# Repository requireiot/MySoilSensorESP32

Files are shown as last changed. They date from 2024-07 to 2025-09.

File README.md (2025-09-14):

MySoilSensorESP32 -- a multi-channel soil moisture sensor with long battery life
----
This is part of my home automation setup. For details, see my [blog](https://requireiot.com/my-home-automation-story-part-1/).

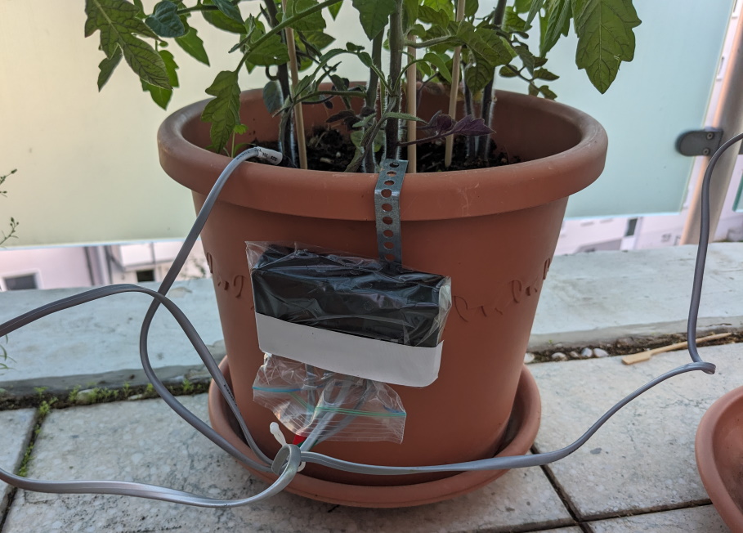
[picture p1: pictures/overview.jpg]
 

- [MySoilSensorESP32 -- a multi-channel soil moisture sensor with long battery life](#mysoilsensoresp32----a-multi-channel-soil-moisture-sensor-with-long-battery-life)
- [Objective](#objective)
- [Design decisions](#design-decisions)
  - [How to make it waterproof-ish](#how-to-make-it-waterproof-ish)
  - [How to communicate](#how-to-communicate)
  - [Minimize power consumption](#minimize-power-consumption)
- [Building blocks](#building-blocks)
- [Hardware](#hardware)
- [Batteries](#batteries)
- [Firmware](#firmware)
- [MQTT messages](#mqtt-messages)
- [Over-the-air update](#over-the-air-update)
  - ['Classic' OTA firmware update](#classic-ota-firmware-update)
  - [OTA firmware download from a HTTP server](#ota-firmware-download-from-a-http-server)
- [Debugging support](#debugging-support)
- [Power consumption and battery life](#power-consumption-and-battery-life)
  - [Wake time](#wake-time)
  - [Actual power consumption](#actual-power-consumption)
- [Lessons learned](#lessons-learned)
  - [Analog-to-digital conversion with the ESP32](#analog-to-digital-conversion-with-the-esp32)
  - [Some things are outside of my control](#some-things-are-outside-of-my-control)
  - [An almost easy project](#an-almost-easy-project)
  - [Bad luck with channel 13](#bad-luck-with-channel-13)

## Objective
In summer, I have a lot of potted plants out on the balcony, and I need to know when 
to water them. Indoors, most of my home automation gadgets are based on 
[MySensors](https://www.mysensors.org/), but out on the balcony the signal is 
too weak, so I needed something WiFi-based, but without the high battery 
consumption typical of WiFi solutions.

## Design decisions

### How to make it waterproof-ish

There will be rain out on the balcony, so the modules need to be waterproof-ish. 
Real waterproof sealed cases are expensive, so I opted for a cheap plastic case 
with a Ziploc bag over it, with the opening facing down ... good enough for the 
intended use case.

### How to communicate

To exchange information between the soil sensors and the home automation system 
(soil moisture and performance characteristics from the device, commands to 
change operating parameters or start over-the-air updates to the device), 
I could think of the following technologies:
1. **MQTT**. *Pro*: I already have an MQTT broker running, and this is independent 
   of a specific home automation system. *Con*: Communication is a bit unpredictable, as I found out
2. **HTTP** requests to a REST API, e.g. for OpenHAB. *Pro*: More deterministic, 
   you know exactly when a message has been accepted. *Con*: Specific for one 
   home automation system

I went for (1).

### Minimize power consumption

- a bare ESP32-WROOM module is better than a development module -- probably due 
  to the voltage regulators and USB interfaces on those modules. Power 
  consumption during deep sleep, with a bare ESP32-WROOM, powered from 2x 
  AAA battery, is under **10µA**.
- to avoid any power loss through a voltage regulator, I am running the ESP32 
  directly from a pair of AAA batteries. Newer processors will work down to 2.3V, 
  I just had to make sure the soil moisture sensor also works below 3V (see below)
- the soil sensors are *powered* by GPIO pins, which are turned off during sleep
- to minimize the time the processor is awake, and in particular the time that 
  WiFi is active, I try to reconnect to WiFi using previously established SSID, 
  IP address and channel number, which are cached in RTC memory

## Building blocks

- an ESP32 module with custom Arduino-based software
- two AAA batteries, which should last for more than a year
- up to 4 cheap capacitive soil sensors, of the kind you find on Aliexpress for 
  less than a Euro
- my home network, with a DHCP server assigning pseudo-static IP addresses to 
  everybody, based on MAC address
- my home automation system, with an MQTT broker and OpenHAB for visualization 
  and control

## Hardware

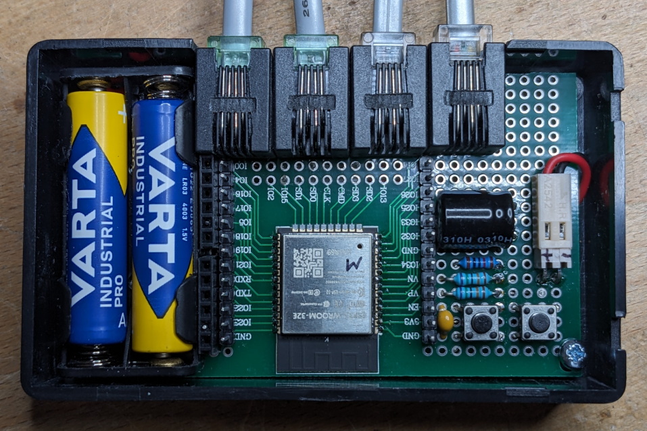
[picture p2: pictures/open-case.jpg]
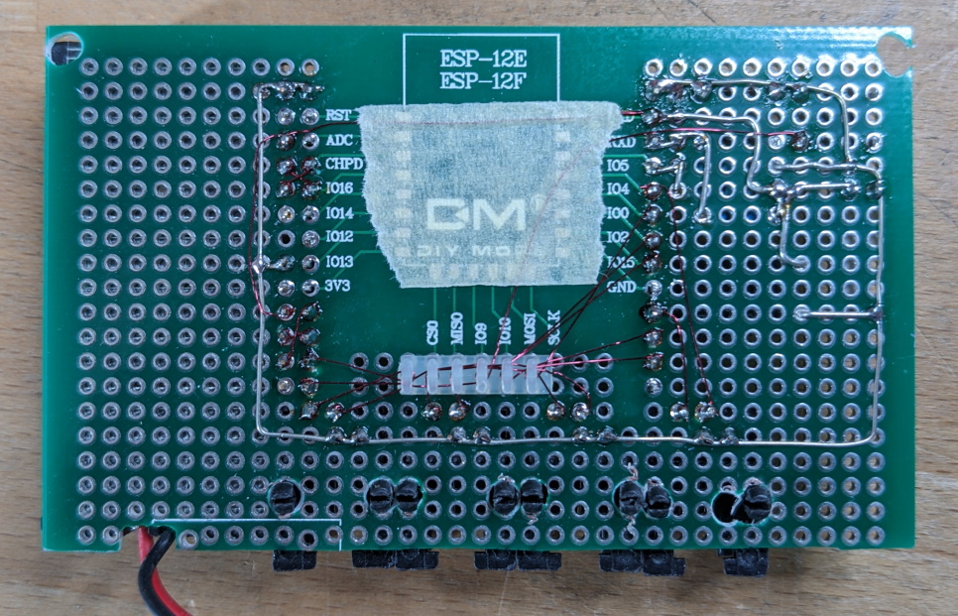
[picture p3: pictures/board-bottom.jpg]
 

The hardware is very simple, see the [schematic](hardware/MySoilSensorESP32.pdf) 
and the pictures above. 

For development and debugging, I added pin connectors to connect to FTDI-232 style 
USB-to-serial interfaces, one for the primary UART (for firmware upload) and one 
for UART#2, where the software outputs logging messages. For a production system, 
this is not necessary and can be left out, of course.

## Batteries

One option is to power the ESP32 directly from two AA or AAA batteries. The battery life calculations reported below apply to this configuration.

As an alternative, I have built a few units with a _rechargable_ battery and a solar panel for charging, attached to the outside of the case. This works as well, if the case can be positioned such that the solar panel faces the sun. Here is the bill of materials for this variant:
* a "5V 75mA 80x45mm" solar panel, from Aliexpress, ca. €1
* a TP4056 battery management module, from Aliexpress, ca. €0.20
* a small Li-ion battery, 3.7V at 1000 mA, from Reichelt (p/n AKKU 30389), €1.80 ... this is a noname replacement battery for some GPS receiver. I have also used a replacement battery for a 1st gen Apple iPod nano.
* a low-drop, low quescent current voltage regulator for 3.3V, HT7833

## Firmware

The software was developed using [Platformio](https://platformio.org/). Just 
download the repository contents into an empty folder, and open that folder as 
a Platformio project. 

In folder `src/`, rename file `myauth_sample.h` to `myauth.h` and enter your 
Wifi SSID and password.

In the top folder, rename file `devices.ini.sample` to `devices.ini` and enter the hostnames and IP addresses for your environment. I built multiple units and wanted to update each of them over-the-air, so I needed a separate entry for each, specifying each IP address as assigned by my DHCP server.

Edit file `platformio.ini` and enter the COM port for your 
environment. 

I used a 7x9 cm prototype board for ESP32 and ESP8266 boards, cut to fit inside 
a 100x60x25 mm plastic case. The soil sensors are connected via cables with an 
RJ12 6P4C connecter on the module end, for easy connection "in the field".

The capacitive soil sensors I got from Aliexpress had an NE555 chip that only 
works down to 3.0V, whereas the ESP32 itself will still work when the battery 
voltage is as low as 2.5V, so I replaced the NMOS NE555 with the CMOS version 
ILC555D, which work down to 2.0V. I also bypassed the voltage regulator on the 
sensor board.

## MQTT messages

The device publishes to MQTT topics that include its own hostname:
- to <code>soil/__hostname__/debug</code> it publishes a JSON string with various 
  internal parameters, such as battery voltage, uptime etc., once every 12 hours
- to <code>soil/__hostname__/state</code> it publishes a JSON string with
   measurement results, once every hour 
- to <code>soil/__hostname__/wifi</code> it publishes a JSON string with some 
  performance metrics, such as Wifi quality, the time needed to connect to the 
  Wifi access point, etc., once every hour 
- it subscribes to <code>soil/__hostname__/cmd</code> to enable over-the-air 
  updates (see below)
- it subscribes to <code>soil/__hostname__/config</code> to receive a JSON-format 
  string enable to change some operating parameters (see source code for details)

For example, my device has the hostname `esp32-D80270`, so it will publish to 
`soil/esp32-D80270/state` etc.

## Over-the-air update

The device supports OTA firmware updates, despite the fact that it is in deep 
sleep most of the time. How? When it wakes up, it subscribes to MQTT topic 
<code>soil/_hostname_/cmd</code> (see above).

### 'Classic' OTA firmware update

When the device wakes up, and it finds a retained MQTT message <code>soil/_hostname_/cmd</code> with the payload of `ota`, it enables ArduinoOTA and waits for an upload of new firmware, instead of going to sleep. 
It also deletes the topic to acknowledge that it has received the command. 

To perform an OTA firmware update,
1. compile your code for the target that has "-ota" in its name (look at 
   `platformio.ini` and adjust the IP address or device hostname to match your 
   conguration)
1. publish a retained message for topic <code>soil/_hostname_/cmd</code> with 
   a payload of `ota` For my device `esp32-D80270`, I run the following shell 
   comand on the home automation server: <br> 
 `mosquitto_pub -r -t "soil/esp32-D80270/cmd" -m "ota"`
1. wait for the item to disappear. I watch it with a tool like 
   [MQTT Explorer](https://mqtt-explorer.com/), or run this shell command 
   repeatedly <br/> `mosquitto_sub -t "soil/esp32-D80270/cmd"`  
1. upload your firmware via Platformio

### OTA firmware download from a HTTP server

When the device wakes up, and it finds a retained MQTT message <code>soil/_hostname_/cmd</code> with the payload of `update`, it attempts to download a new firmware file named <code>_hostname_-firmware.bin</code> from a HTTP server on the local network. The server name can be configured in source code. After a successful download, it will install the new firmware and the restart. It also deletes the topic to 
acknowledge that it has received the command. 

To perform this kind of OTA firmware update,
1. compile your code for the `env:http` target 
2. when you "upload", the `firmware.bin` file will just be copied to your HTTP server, and renamed to <code>MySoilSensorESP32.bin</code>. 
3. publish a retained message for topic <code>soil/_hostname_/cmd</code> with 
   the payload of `update` For my device `esp32-D80270`, I run the following shell 
   comand on the home automation server: <br> 
 `mosquitto_pub -r -t "soil/esp32-D80270/cmd" -m "update"`
1. The next time the module wakes up, it will perform the update. You can tell that the update has happened when the MQTT item disappears. I watch it with a tool like [MQTT Explorer](https://mqtt-explorer.com/), or run this shell command 
   repeatedly <br/> `mosquitto_sub -t "soil/esp32-D80270/cmd"`  

The advantage of this type of OTA update is that you can build firmware for multiple devices, publish the <code>soil/_hostname_/cmd</code> topic for each device, and then go away and forget about it. Each device will update itself the next time it wakes up as scheduled.

## Debugging support

The software can print a lot of logging messages to UART#2 (GPIO pins 16 and 17), 
to which I connect an optically isolated FTDI-style USB to serial module. This 
was really helpful for understanding what goes on, and where delays occur.

The logging messages are normally suppressed. To enable logging, edit `platformio.ini`, in the general `[env]` section or an `[env:xyz]` section for a specific device, to contain
```
build_flags = 
  -D CORE_DEBUG_LEVEL=3
```

## Power consumption and battery life

### Wake time

As explained above, the time the module stays awake each measurement cycle is 
important for overall power consumption, so I investigated the wake time in some 
detail.

I built several of these units, some connected directly to the Wifi access point 
(a AVM Fritzbox 7530), and some via a Wifi repeater (a Fritzbox 7490 operating as a mesh repeater), over a distance of 3-5m, through a massive outer brick wall (or maybe through a 
window).

On average, the wake time is about **1000 ms** for all units. Now and then, maybe 
once or twice a day, the wake time is much larger, above **1500 ms**. This appeared
to happen mostly when the Wifi access point had switched to a different Wifi 
channel. When I configured my access point to use a fixed Wifi channel, these 
long wake time events became less frequent.

### Actual power consumption

These factors contribute to power consumption or battery drain, 
in decreasing order of importance:
1. the self-discharge of the AAA batteries, according to [[1]](http://www.gammon.com.au/power), 
about 35 µA or **0.84 mAh** per day 
1. wake time with WiFi ON, 140 mA x ~600ms per wakeup or **0.56 mAh** per day
1. deep sleep, at ~8 µA or **0.2 mAh** per day
1. wake time, with WiFi OFF, 40 mA x ~600ms per wakeup or **0.16 mAh** per day

This adds up to a charge of 106mC per wake period, which closely matches an actual measurement with a [Nordic Power Profiler](https://www.nordicsemi.com/Products/Development-hardware/Power-Profiler-Kit-2).

We have brought the design to the point where overall power consumption is 
dominated by the self-dischange of the Alkaline batteries, so there is no point 
in attempting to further optimize the power consumption of the processor module.

## Lessons learned

### Analog-to-digital conversion with the ESP32

The ADC on the ESP32 module has a bad reputation, there are many websites and 
forum posts that document its bad linearity and high noise level. For this 
application, the inferior performance is acceptable, because we are not attempting 
to make high precision measurements, just give an indication of "soil is ok" vs 
"soil is too dry".

### Some things are outside of my control

The performance of the device, in terms of power consumption or battery life, 
depends of course on the design of the device itself and the design decisions I 
made (processor, program flow, etc.), but also on external factors that I cannot 
control. For example, power consumption depends on wake time, which is the 
aggregate of
* the time between turning on sensor power, and measuring the sensor voltage -- 
  I chose *150ms*, which appears to be enough for the sensor voltage to settle
* the time to re-connect to the Wifi access point, using stored information 
  about WiFi channel, SSID etc -- this takes about *350-550* most of the time, 
  but sometimes can take as much as 2-3s
* the time to look up the IP address for the MQTT broker, usually *20-40ms*
* the time to connect to the MQTT broker, mostly *30ms*, but sometimes up to 
  *500ms*, which I can't explain
* the time to send MQTT messages -- I can influence this, by deciding how much 
  information to send
* the time to disconnect from the Wifi access point -- mostly about *20ms*, 
  but sometimes more than *100ms*, which I can't explain

### An almost easy project

I found it fairly easy to create a first version of the code that sort of worked 
most of the time. Then I began to notice the rough edges, and it took a lot of 
time to get those fixed:
* *easy*: making measurements and reporting them via MQTT. *Harder*: get the 
  measurements to be less jittery, and less affected by varying current 
  consumption due to WiFi activity 
* allow configuration changes via MQTT, and acknowledge the command by deleting 
  the topic. *Easy*: get it to work most of the time, with occasional loss of a 
  message. *Harder*: make it work every time, by inserting delays here and there, 
  without a massive increase in the overall wake time

### Bad luck with channel 13

When the WiFi router is set to channel 12 or 13, connection time is much higher 
(>2000ms) than on WiFi channel 1-11 (300-500ms) ... didn't expect that, should 
have read [this](https://olimex.wordpress.com/2021/12/10/avoid-wifi-channel-12-13-14-when-working-with-esp-devices/) before!

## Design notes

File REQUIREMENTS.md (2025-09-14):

MySoilSensorESP32 - Multi-channel soil moisture sensor
====

- [Objectives](#objectives)
- [Use Case](#use-case)
- [Requirements](#requirements)
  - [Connectivity](#connectivity)
  - [Hardware](#hardware)
  - [Measurements](#measurements)
  - [Reports](#reports)
  - [Configuration](#configuration)
  - [Remote management](#remote-management)
- [Architecture](#architecture)
- [Mechanical design](#mechanical-design)

## Objectives
* get information about soil moisture, to drive decision when to water a plant
* deal with variability in placement of sensor within a pot, 
  resulting in differing range of measured values etc.

## Use Case
* monitor soil moisture of multiple pots using *one* gadget, with a durable sensor stuck in each pot

## Requirements

### Connectivity
- [x] `R001` the device has a wireless connection to the home automation system, 
  via WiFi. <br>*Rationale:* decide against MySensors RF24 because of range concerns, 
  and because it would not support MQTT
  - [x] `R001.1` when using Wifi, the SSID and password are configurable in source code
- [x] `R002` the device communicates via MQTT
  - [x] `R002.1` the MQTT broker name and port are configurable in source code
- [x] `R003` the device supports over-the-air software updates
- [x] `R004' device behavior can be configured over-the-air (details below, in 
  *configuration* section)
- [x] `R005` the device receives runtime configuration instructions via MQTT
  - [x] `R005.1` it is acceptable that the device polls for runtime configuration 
  instructions only when it wakes up for measurements. This means that the 
  configuration instructions must be published as *retained* messages.
  - [x] `R005.2` the device acknowledges receipt of runtime configuration 
  information by deleting the MQTT topic

### Hardware
- [x] `R010` the device runs on batteries
- [x] `R011` if non-rechargeable batteries are used, they must last for at least 
  a year
- [ ] `R012` if rechargeable batteries are used, they must be rechargeable via a 
  solar panel

### Measurements
- [x] `R020` the device connects to at least 4 soil sensors
- [x] `R021` the device is compatible with capacitive soil sensors
- [x] `R022` the device measures the *absolute* voltage output by each sensor, in 
  millivolts
- [x] `R023` the device detects when a sensor is disconnected
  - [x] `R023.1` when a sensor is disconnected, the device resets the range of 
  observed voltages
  - [x] `R023.2` while a sensor is disconnected, measurement values do not 
  contribute to the "observed range 
- [x] `R024` while a meaningful range of sensor voltages has been observed, the 
  device also calculates *relative* moisture. 
  - [x] `R024.1` *Design decision*: "meaningful" range is 5% of the maximum ADC 
  - [x] `R024.2` *relative* moisture is calculated as a fraction of the observed 
  voltage range, with smaller values indicating dry soil, and vice versa 
- [x] `R025` the device measures the battery voltage, which may be up to 4.7V

### Reports
- [x] `R030` all reports are made as MQTT messages, in a format the can be easily 
  parsed by OpenHAB
- [x] `R031` the device reports absolute voltage measurements of sensor outputs, 
  in millivolts
- [x] `R032` the device reports relative moisture measurements (see above), on a 
  scale of 0 to 1000 (i.e.promille of observed range)
- [x] `R033` the device reports relevant parameters of its internal status
- [x] `R034` the device reports the battery voltage
- [x] `R035` the device reports Wifi connection quality ("RSSI") on a scale of 
  0 to 100, with 100 being the best quality
- [x] `R036` the device reports the number of times it has woken up from deep sleep
- [x] `R037` the device reports the total time it has been operational since 
  power-up, including sleep times
- [x] `R038` the device reports the time it was awake to make a measurement, 
  in milliseconds, after each wake period
- [x] `R039` the device reports the time it took to connect to Wifi, 
  in milliseconds, after each wake period

### Configuration 
- [x] `R040` the interval between measurement reports is configurable in source 
  code, between 1 min and 1 hour
- [x] `R041` the interval between device status reports is configurable in source 
  code, between the measurements report interval and 24h
- [x] `R042` the interval between measurement reports can be changed at runtime
- [x] `R043` the interval between device status reports can be changed at runtime

### Remote management
- [x] `R050` the device can update its firmware over-the-air, by downloading new firmware from a HTTP server on the local network
  - [x] `R050.1` the device downloads a device-specific firmware file
  - [x] `R050.2` the over-the-air firmware update can be triggered by setting a device-specific MQTT topic
- [x] `R051` the range for *relative* moisture calculation can be reset at runtime
  - [x] `R051.1` reset of the range is triggered by setting a device-specific MQTT topic
  - [ ] `R051.2` the range for *relative* moisture calculation can be reset 
  independently for each channel 

## Architecture
- [x] `R101` the device uses cheap Aliexpress sourced capacitive soil moisture 
  sensors based on a 555 oscillator
- [x] `R102` the device uses a Wifi-capable processor, i.e. ESP32. <br>
  *Rationale:* ability to work outside MySensors range
- [x] `R102` the device uses 2 AAA batteries. <br>*Rationale:* only way to 
  satisfy battery life requirements

## Mechanical design
- [x] `R103` the connection from sensor to device can be up to 60cm long. 
  *Rationale*: balcony flower boxes are 60cm wide, and a device can sit between 
  2 flower boxes
- [x] `R104` the connection from sensor to device is easy to disconnect 
  "in the field"
- [x] `R105` the connection from sensor to device uses cheap (<0.5€) connectors. 
  <br>*Solution:* RJ12 6P4C connectors
- [x] `R106` the connector from sensor cable to device need not be waterproof. 
  <br>*Rationale:* rain protection is achieved by other means, protecting the 
  entire device.

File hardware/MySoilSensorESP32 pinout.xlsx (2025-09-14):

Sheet: Sheet1
 |  |  |  |  |  |  |  | WROOM Module |  |  |  |  |  |  |  |  |  | ESP32-S3 WROOM-1
 |  |  |  |  |  |  | GND | Antenna | GND |  |  |  |  |  |  |  | GND | Antenna | GND
 |  |  |  |  |  |  | 3V3 |  | io23 | pullup |  | MOSI |  |  | ok for GPIO |  | 3V3 |  | io1
 |  |  |  |  |  |  | EN |  | io22 | pullup |  | SCL |  |  | ok for GPIO |  | EN |  | io2
 | battery voltage | RTC io0 |  |  | ADC1_0 | inp only | io36,VP |  | TxD0 |  |  |  |  |  |  |  | io4 |  | TxD0
 | Sensor 1 | RTC io3 |  |  | ADC1_3 | inp only | io39,VN |  | RxD0 |  |  |  |  |  |  |  | io5 |  | RxD0
 | Sensor 2 | RTC io4 |  |  | ADC1_6 | inp only | io34 |  | io21 | pullup |  | SDA |  |  | ok for GPIO |  | io6 |  | io42
 | Sensor 3 | RTC io5 |  |  | ADC1_7 | inp only | io35 |  | nc |  |  |  |  |  |  |  | io7 |  | io41 | was nc
ok for GPIO | Sensor 4 | RTC io9 | Touch 9 |  | ADC1_4 | no pu | io32 |  | io19 | pullup |  | MISO |  |  | ok for GPIO |  | io15 |  | io40
ok for GPIO | Sensor 5 | RTC io8 | Touch 8 |  | ADC1_5 | no pu | io33 |  | io18 | pullup |  | SCK |  |  | ok for GPIO |  | io16 |  | io39
ok for GPIO | Power 1 | RTC io6 |  | DAC 1 | ADC2_8 | no pu | io25 |  | io5 | pull-up |  | SS |  |  | strapping pin |  | io17 |  | io38
ok for GPIO | Power 2 | RTC io7 |  | DAC 2 | ADC2_9 | no pu | io26 |  | io17 | pullup |  | TxD 2 |  |  | ok for GPIO |  | io18 |  | io37
ok for GPIO | Power 3 | RTC io17 | Touch 7 |  | ADC2_7 | no pu | io27 |  | io16 | pullup |  | RxD 2 |  |  | ok for GPIO |  | io8 |  | io36
output signal at boot |  | RTC io16 | Touch 6 | MTMS | ADC2_6 | pullup | io14 |  | io4 |  | ADC2_0 |  | Touch 0 | Power 5 | ok for GPIO | USB D- | io19 |  | io35
strapping pin |  | RTC io15 | Touch 5 | MTDI | ADC2_5 |  | io12 |  | io0 | pull-up | ADC2_1 |  | Touch 1 | BOOT |  | USB D+ | io20 |  | io0 | BOOT
 |  |  |  |  |  |  | GND |  | io2 | pull-down | ADC2_2 |  | Touch 2 |  | float or LOW to flash |  | io3 |  | io45 | pd
ok for GPIO | Power 4 | RTC io14 | Touch 4 | MTCK | ADC2_4 | no pu | io13 |  | io15 |  | ADC2_3 | MTDO | Touch 3 |  | output signal at boot | was GND | io46 |  | io48
 |  |  |  | Flash |  |  | io9 |  | io8 |  |  | Flash |  |  |  |  | io9 |  | io47
 |  |  |  | Flash |  |  | io10 |  | io7 |  |  | Flash |  |  |  |  | io10 |  | io21
 |  |  |  | Flash |  |  | io11 |  | io6 |  |  | Flash |  |  |  |  | io11 |  | io14
 |  |  |  |  |  |  |  |  |  |  |  |  |  |  |  |  | io12 |  | io13
 |  |  |  |  |  |  | Serial 1 default 12,14 must remap
 |  |  |  |  |  |  | Serial 2 default 16,17 can remap

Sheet: I2S
Device | I2C SCL | I2C SDA | mic | mic MCLK | mic BCLK | mic WS | mic DI | I2C addr | spk | spk MCLK | spk BCLK | spk WS | spk DO | I2C addr | AMP ctrl | comments
Inmp441 Max98357a FastLed |  |  | INMP441 |  | 25 | 32 | 33 |  | MAX98357A |  | 14 | 12 | 27
AudioKit | 32 | 33 | ES8388 |  | 27 | 25 |  | 16 | ES8388 |  | 27 | 25 | 26 | 16 | 21 | ESP32A1S V2.2+ variant 1 (ES8388)
ESP32-S3-Box-lite | 18 | 8 | ES7243E | 2 | 17 | 47 | 16 | 16 | ES8156 | 2 | 17 | 47 | 15 | 8 | 46
ESP32-S3-Box | 18 | 8 | ES7210 | 2 | 17 | 47 | 16 |  | ES8311 | 2 | 17 | 47 | 15 | 0x40 | 46

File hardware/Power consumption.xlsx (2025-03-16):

ESP32-WROOM, 3x AAA 4.5V
State | Duration [µs] | Duration [ms] | Current [mA] | Current [µA] | repeat /day | total time [s] | total [mAh] | I avg [mA]
Active, Wifi off |  | 400 | 41 |  | 24 | 9.6 | 0.11 | 0.004555555556 |  | 4.5 | V Bat | 3 | V supply
Active, Wifi on |  | 600 | 140 |  | 24 | 14.4 | 0.56 | 0.02333333333 |  |  |  | 200 | kOhm pulldown
battery monitor |  |  |  | 4.8 |  | 86400 | 0.11 | 0 |  | 470 | kOhm | 15 | µA current per channel
sleep |  |  |  | 14 |  | 86390.4 | 0.34 | 0.000 |  | 470 | kOhm | 4 | channels
self discharge |  |  |  | 35 |  | 86400 | 0.84 |  |  | 2.25 | V max ADC in | 60 | µA current total
 |  |  |  |  |  |  | 1.96 | mAh / day |  | 4.8 | µA
 |  |  |  |  |  |  | 1250 | mAh AAA battery
 |  |  |  |  |  |  | 75% | of capacity is usable |  | 2.45 | V max ESP32 in
 |  |  |  |  |  |  | 478.2700571 | days
 |  |  |  |  |  |  | 1.3 | years
ESP32-WROOM, 2x AAA 3.0V
State | Duration [µs] | Duration [ms] | Current [mA] | Current [µA] | repeat /day | total time [s] | total [mAh] | I avg [mA] | charge [mC]
Active, Wifi off |  | 400 | 41 |  | 24 | 9.6 | 0.11 | 0.004555555556 | 16.4 | 3 | V Bat | 87 | mC per wake, measured
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

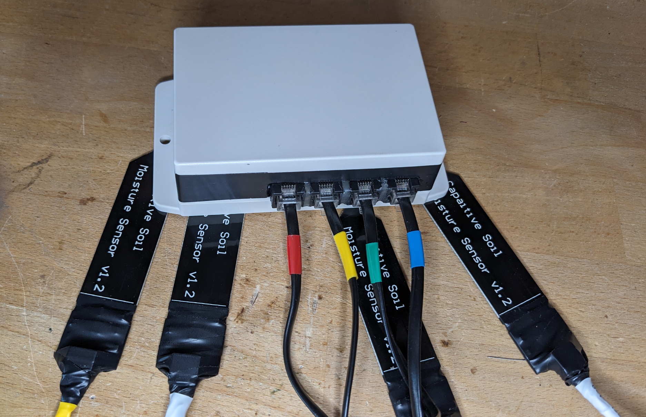
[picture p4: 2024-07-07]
pictures/K/overview.jpg

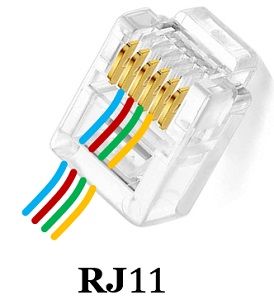
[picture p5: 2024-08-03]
hardware/RJ11new.jpg

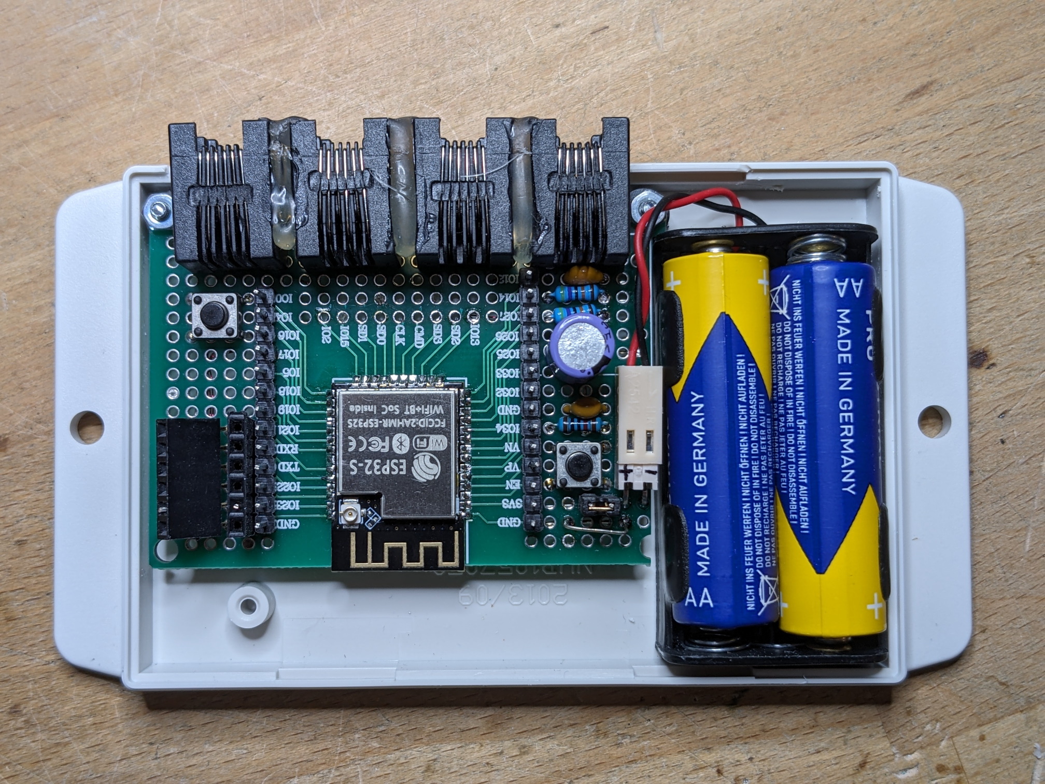
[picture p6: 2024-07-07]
pictures/K/open-case.jpg

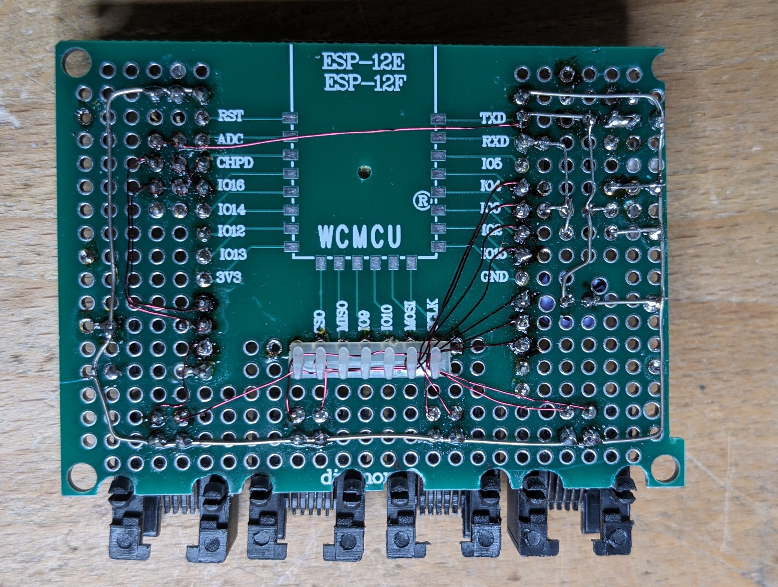
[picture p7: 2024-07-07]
pictures/K/board-bottom.jpg

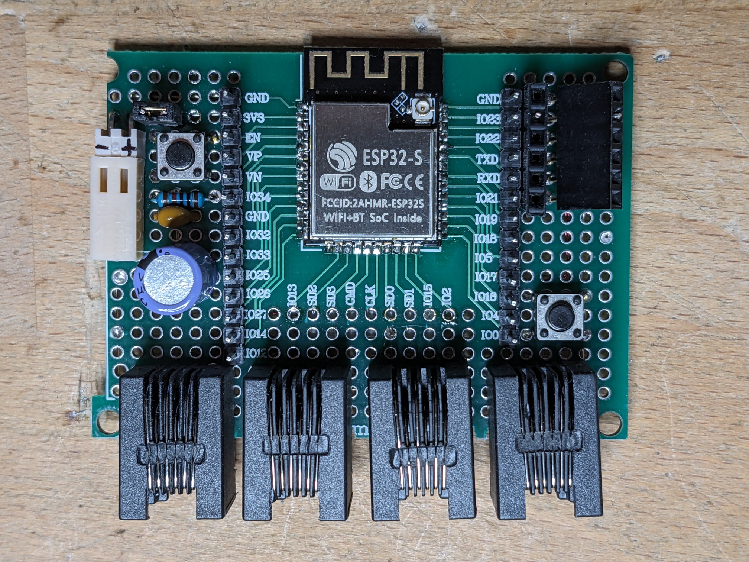
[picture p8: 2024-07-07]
pictures/K/board-top.jpg

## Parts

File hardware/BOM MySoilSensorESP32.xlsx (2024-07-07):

Item | qty | lot size | €/lot | €/pc | cost | vendor | part #
ESP32-WROOM-32E | 1 | 1 | 2.52 € | 2.52 € | 2.52 € | Aliexpress | ali YX Electronic Components
Prototype PCB for ESP8266 | 1 | 1 | 1.64 € | 1.64 € | 1.64 € | Aliexpress | 7x9CM 70X90mm Prototype PCB Breadboard Board For ESP
100x60x25mm case | 1 | 5 | 5.04 € | 1.01 € | 1.01 € | Aliexpress
2x AAA battery holder | 1 | 10 | 3.03 € | 0.30 € | 0.30 € | Aliexpress | AAA Battery Holder With Leads, 2AAA 10PCS
1uF ceramic | 3 | 100 | 1.11 € | 0.01 € | 0.03 € | Aliexpress
470µF | 1 | 1 | 0.14 € | 0.14 € | 0.14 € | Reichelt | M-A 1,0M 16
RJ12 socket | 4 | 10 | 2.26 € | 0.23 € | 0.90 € | Aliexpress
RJ12 plug 6p4c | 4
JST connector 3-pin | 4 | 100 | 2.50 € | 0.03 € | 0.10 € | Aliexpress
Capacitive Soil Moisture Sensor Module | 4 | 5 | 3.80 € | 0.76 € | 3.04 € | Aliexpress
ILC555D | 4 | 1 | 0.25 € | 0.25 € | 1.00 € | Reichelt
 |  |  |  |  | 10.69 €

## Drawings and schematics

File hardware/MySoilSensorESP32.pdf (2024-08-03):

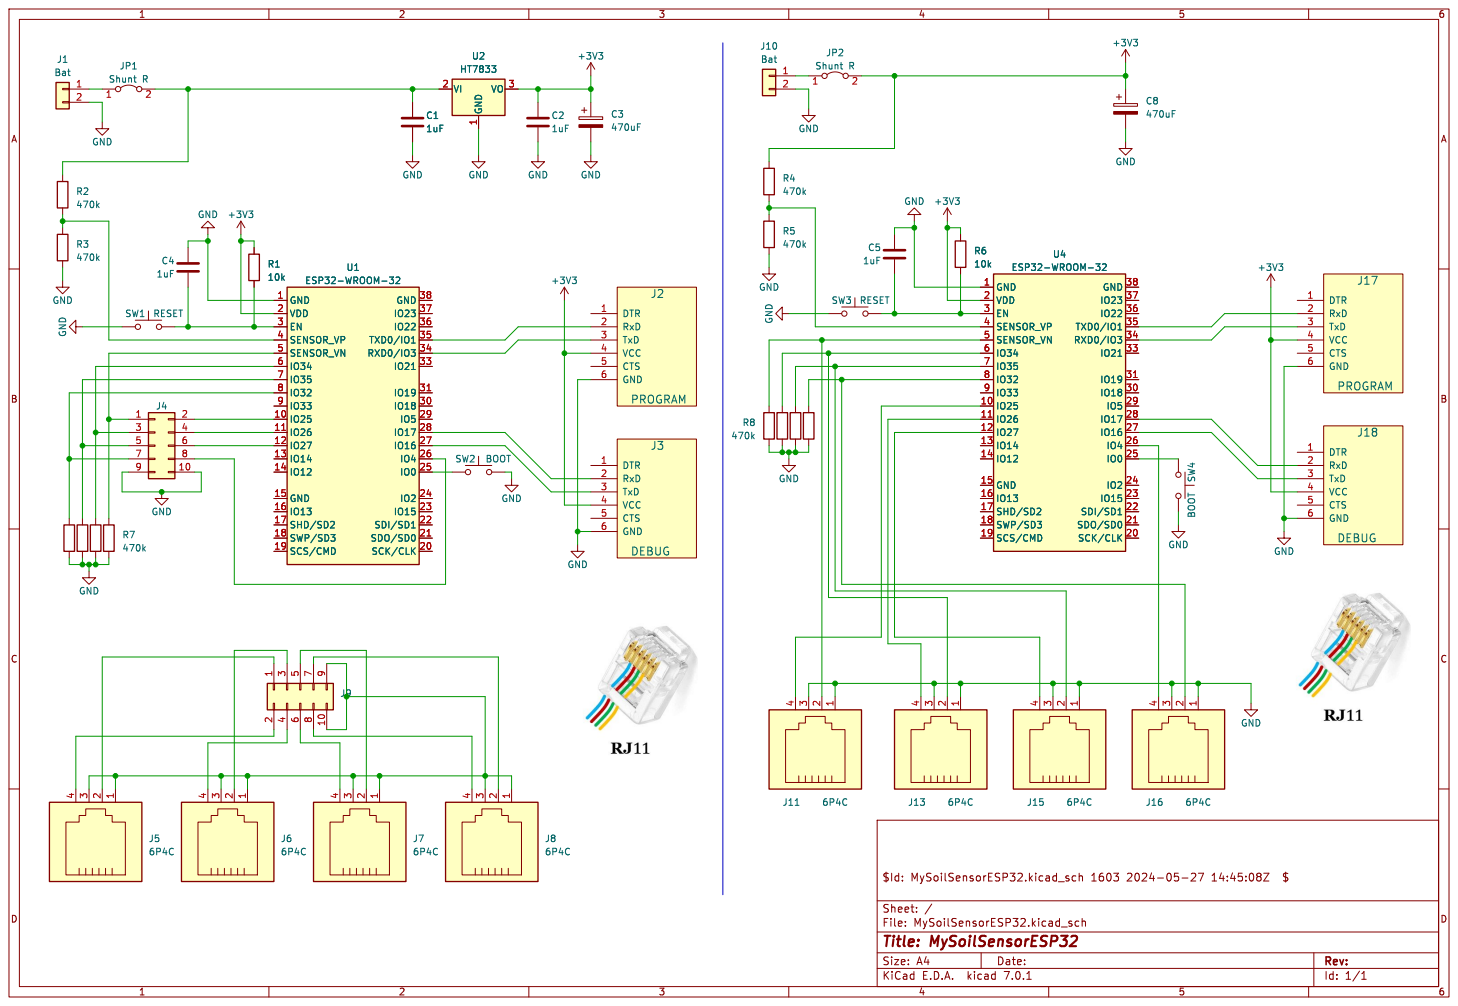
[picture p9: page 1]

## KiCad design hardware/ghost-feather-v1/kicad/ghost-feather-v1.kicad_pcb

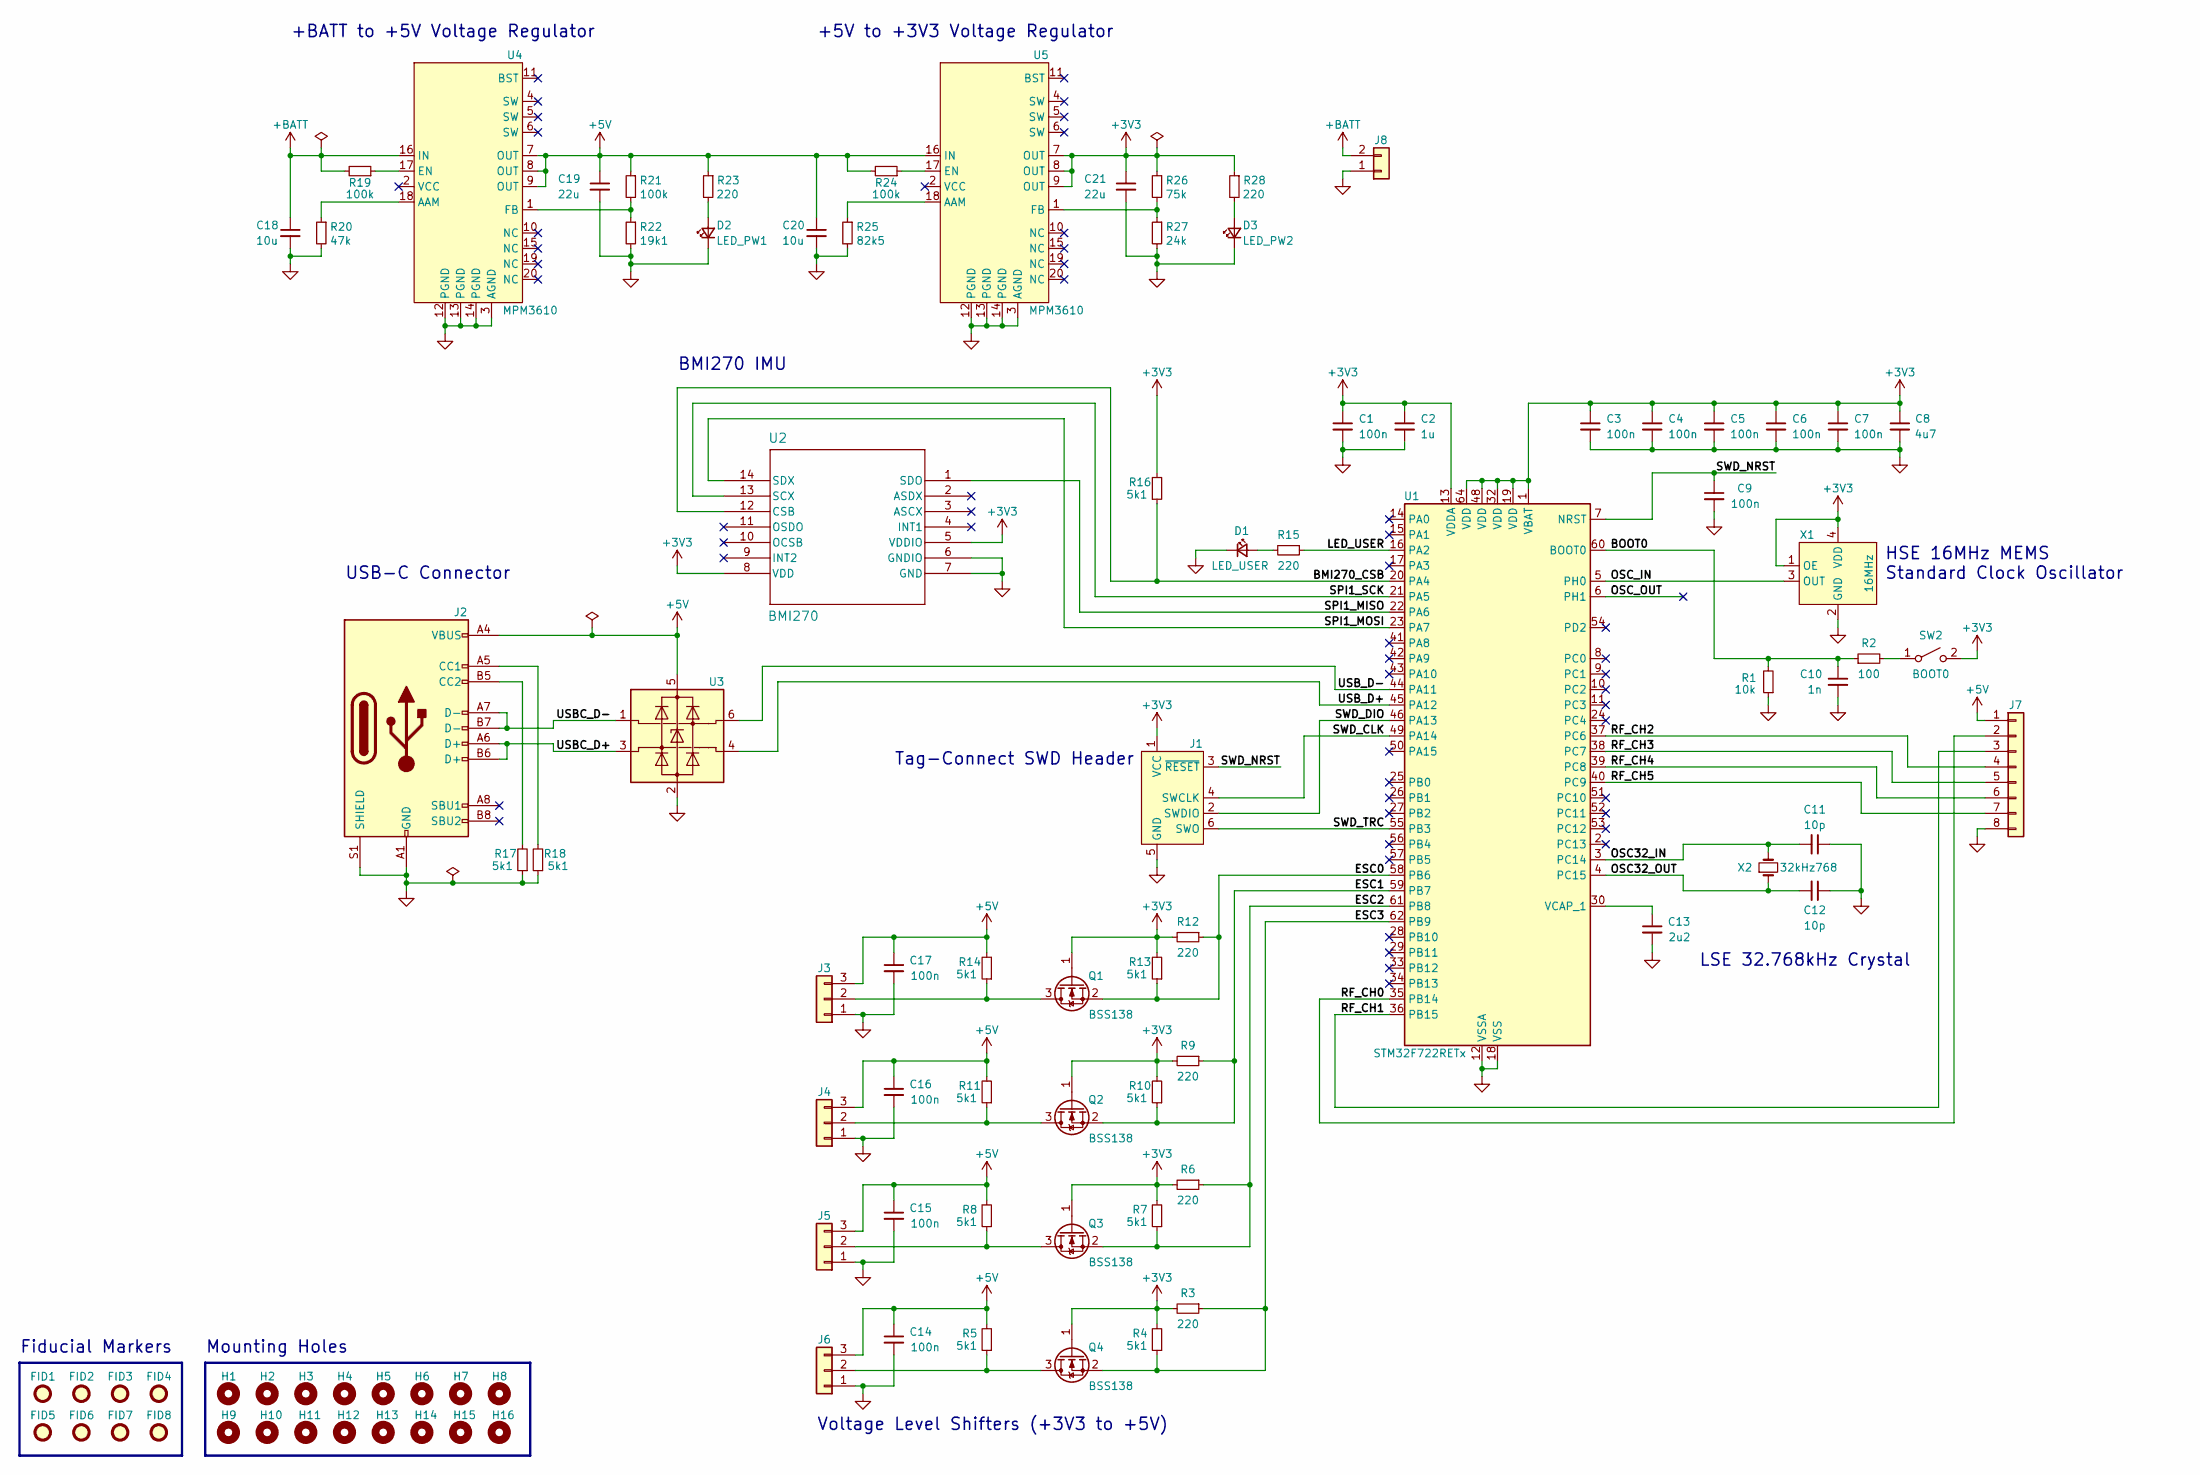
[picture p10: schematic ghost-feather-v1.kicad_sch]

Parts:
C1, C3, C4, C5, C6, C7, C9, C14, C15, C16, C17: 100n; C_0402_1005Metric
C2: 1u; C_0603_1608Metric
C8: 4u7; C_0603_1608Metric
C10: 1n; C_0402_1005Metric
C11, C12: 10p; C_0402_1005Metric
C13: 2u2; C_0603_1608Metric
C18, C20: 10u; C_0603_1608Metric
C19, C21: 22u; C_0603_1608Metric
D1: LED_USER; LED_0402_1005Metric; Manufacturer Part Number SML-P11VTT86R
D2: LED_PW1; LED_0402_1005Metric; Manufacturer Part Number SML-P11VTT86R
D3: LED_PW2; LED_0402_1005Metric; Manufacturer Part Number SML-P11VTT86R
FID1, FID2, FID3, FID4, FID5, FID6, FID7, FID8: Fiducial; Fiducial_1.5mm_Mask4.5mm
H1, H2, H3, H4, H5, H6, H7, H8, H9, H10, H11, H12, H13, H14, H15, H16: MountingHole; MountingHole_2.7mm_M2.5
J1: Conn_ARM_SWD_TagConnect_TC2030; Tag-Connect_TC2030-IDC-FP_2x03_P1.27mm_Vertical
J2: USB_C_Receptacle_USB2.0; USB_C_Receptacle_GCT_USB4105-xx-A_16P_TopMnt_Horizontal
J3, J4, J5, J6: Conn_01x03; Molex_PicoBlade_53048-0310_1x03_P1.25mm_Horizontal; Manufacturer Part Number 53048-0310
J7: Conn_01x08; Molex_PicoBlade_53048-0810_1x08_P1.25mm_Horizontal; Manufacturer Part Number 53048-0810
J8: Conn_01x02; AMASS_XT60PW-M_1x02_P7.20mm_Horizontal
Q1, Q2, Q3, Q4: BSS138; SOT-23
R1: 10k; R_0402_1005Metric
R2: 100; R_0402_1005Metric
R3, R6, R9, R12, R15, R23, R28: 220; R_0402_1005Metric
R4, R5, R7, R8, R10, R11, R13, R14, R16, R17, R18: 5k1; R_0402_1005Metric
R19, R21, R24: 100k; R_0402_1005Metric
R20: 47k; R_0402_1005Metric
R22: 19k1; R_0402_1005Metric
R25: 82k5; R_0402_1005Metric
R26: 75k; R_0402_1005Metric
R27: 24k; R_0402_1005Metric
SW2: BOOT0; SW_SPST_EVQPE1
U1: STM32F722RETx; LQFP-64_10x10mm_P0.5mm; Manufacturer Part Number STM32F722RET6
U2: BMI270; BMI270_BOS; Manufacturer Part Number BMI270
U3: USBLC6-2SC6_MOD; SOT-23-6; Manufacturer Part Number USBLC6-2SC6
U4, U5: MPM3610
X1: 16MHz; AMPMGFB_1.6mm1.2mm_16MHz; Manufacturer Part Number AMPMGFB-16.0000T
X2: 32kHz768; CC4V-T1A-32.768kHz; Manufacturer Part Number CC4V-T1A-32.768kHz-10pF-20PPM-TA-QC

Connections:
+3V3: C1.1, C2.1, C3.1, C4.1, C5.1, C6.1, C7.1, C8.1, C21.1, J1.1 (VCC), Q1.1 (G), Q2.1 (G), Q3.1 (G), Q4.1 (G), R3.2, R4.2, R6.2, R7.2, R9.2, R10.2, R12.2, R13.2, R16.2, R26.1, R28.1, SW2.2 (B), U1.1 (VBAT), U1.13 (VDDA), U1.19 (VDD), U1.32 (VDD), U1.48 (VDD), U1.64 (VDD), U2.5 (VDDIO), U2.8 (VDD), U5.7 (OUT), U5.8 (OUT), U5.9 (OUT), X1.1 (OE), X1.4 (VDD)
+5V: C14.1, C15.1, C16.1, C17.1, C19.1, C20.1, J2.A4 (VBUS), J2.A9 (VBUS), J2.B4 (VBUS), J2.B9 (VBUS), J3.3, J4.3, J5.3, J6.3, J7.1, R5.2, R8.2, R11.2, R14.2, R21.1, R23.1, R24.2, U3.5 (VBUS), U4.7 (OUT), U4.8 (OUT), U4.9 (OUT), U5.16 (IN)
+BATT: C18.1, J8.2, R19.2, U4.16 (IN)
/BMI270_CSB: R16.1, U1.20 (PA4), U2.12 (CSB)
/BOOT0: C10.1, R1.2, R2.1, U1.60 (BOOT0)
/ESC0: Q1.2 (S), R12.1, R13.1, U1.58 (PB6)
/ESC1: Q2.2 (S), R9.1, R10.1, U1.59 (PB7)
/ESC2: Q3.2 (S), R6.1, R7.1, U1.61 (PB8)
/ESC3: Q4.2 (S), R3.1, R4.1, U1.62 (PB9)
/LED_USER: R15.1, U1.16 (PA2)
/OSC32_IN: C11.2, U1.3 (PC14), X2.2
/OSC32_OUT: C12.2, U1.4 (PC15), X2.1
/OSC_IN: U1.5 (PH0), X1.3 (OUT)
/OSC_OUT: U1.6 (PH1)
/RF_CH0: J7.2, U1.35 (PB14)
/RF_CH1: J7.3, U1.36 (PB15)
/RF_CH2: J7.4, U1.37 (PC6)
/RF_CH3: J7.5, U1.38 (PC7)
/RF_CH4: J7.6, U1.39 (PC8)
/RF_CH5: J7.7, U1.40 (PC9)
/SPI1_MISO: U1.22 (PA6), U2.1 (SDO)
/SPI1_MOSI: U1.23 (PA7), U2.14 (SDX)
/SPI1_SCK: U1.21 (PA5), U2.13 (SCX)
/SWD_CLK: J1.4 (SWCLK), U1.49 (PA14)
/SWD_DIO: J1.2 (SWDIO), U1.46 (PA13)
/SWD_NRST: C9.1, J1.3 (~RESET), U1.7 (NRST)
/SWD_TRC: J1.6 (SWO), U1.55 (PB3)
/USBC_D+: J2.A6 (D+), J2.B6 (D+), U3.3 (I/O1)
/USBC_D-: J2.A7 (D-), J2.B7 (D-), U3.1 (I/O1)
/USB_D+: U1.45 (PA12), U3.4 (I/O2)
/USB_D-: U1.44 (PA11), U3.6 (I/O2)
GND: C1.2, C2.2, C3.2, C4.2, C5.2, C6.2, C7.2, C8.2, C9.2, C10.2, C11.1, C12.1, C13.2, C14.2, C15.2, C16.2, C17.2, C18.2, C19.2, C20.2, C21.2, D1.1 (K), D2.1 (K), D3.1 (K), J1.5 (GND), J2.A1 (GND), J2.A12 (GND), J2.B1 (GND), J2.B12 (GND), J2.S1 (SHIELD), J3.1, J4.1, J5.1, J6.1, J7.8, J8.1, R1.1, R17.1, R18.1, R20.2, R22.2, R25.2, R27.2, U1.12 (VSSA), U1.18 (VSS), U1.31 (VSS), U1.47 (VSS), U1.63 (VSS), U2.6 (GNDIO), U2.7 (GND), U3.2 (GND), U4.3 (AGND), U4.12 (PGND), U4.13 (PGND), U4.14 (PGND), U5.3 (AGND), U5.12 (PGND), U5.13 (PGND), U5.14 (PGND), X1.2 (GND)
unnamed: D1.2 (A), R15.2
unnamed: D2.2 (A), R23.2
unnamed: D3.2 (A), R28.2
unnamed: J2.A5 (CC1), R18.2
unnamed: J2.B5 (CC2), R17.2
unnamed: J3.2, Q1.3 (D), R14.1
unnamed: J4.2, Q2.3 (D), R11.1
unnamed: J5.2, Q3.3 (D), R8.1
unnamed: J6.2, Q4.3 (D), R5.1
unnamed: R2.2, SW2.1 (A)
unnamed: C13.1, U1.30 (VCAP_1)
unnamed: R20.1, U4.18 (AAM)
unnamed: R19.1, U4.17 (EN)
unnamed: R21.2, R22.1, U4.1 (FB)
unnamed: R25.1, U5.18 (AAM)
unnamed: R24.1, U5.17 (EN)
unnamed: R26.2, R27.1, U5.1 (FB)

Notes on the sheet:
HSE 16MHz MEMS Standard Clock Oscillator
Tag-Connect SWD Header
BMI270 IMU
LSE 32.768kHz Crystal
USB-C Connector
Voltage Level Shifters (+3V3 to +5V)
+5V to +3V3 Voltage Regulator
+BATT to +5V Voltage Regulator
Fiducial Markers
Mounting Holes

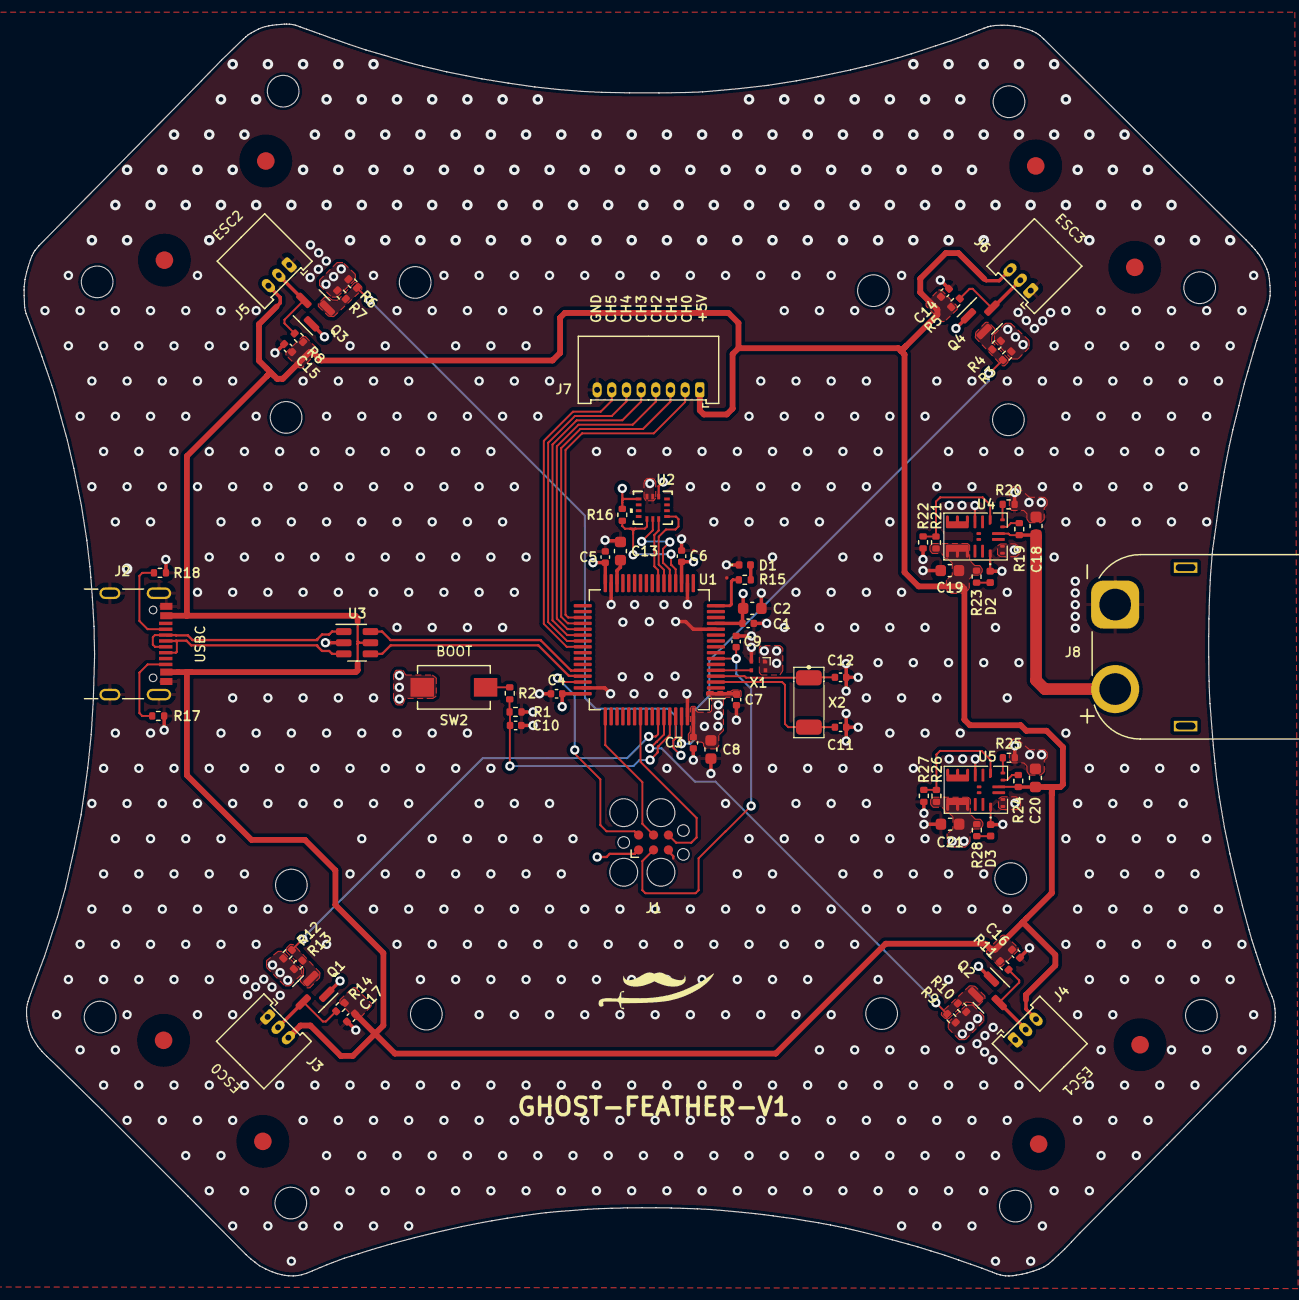
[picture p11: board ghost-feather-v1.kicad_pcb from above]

Board: 4 copper layers, 106.6 x 106.7 mm, 96 parts (0 on the bottom side), 48 nets.

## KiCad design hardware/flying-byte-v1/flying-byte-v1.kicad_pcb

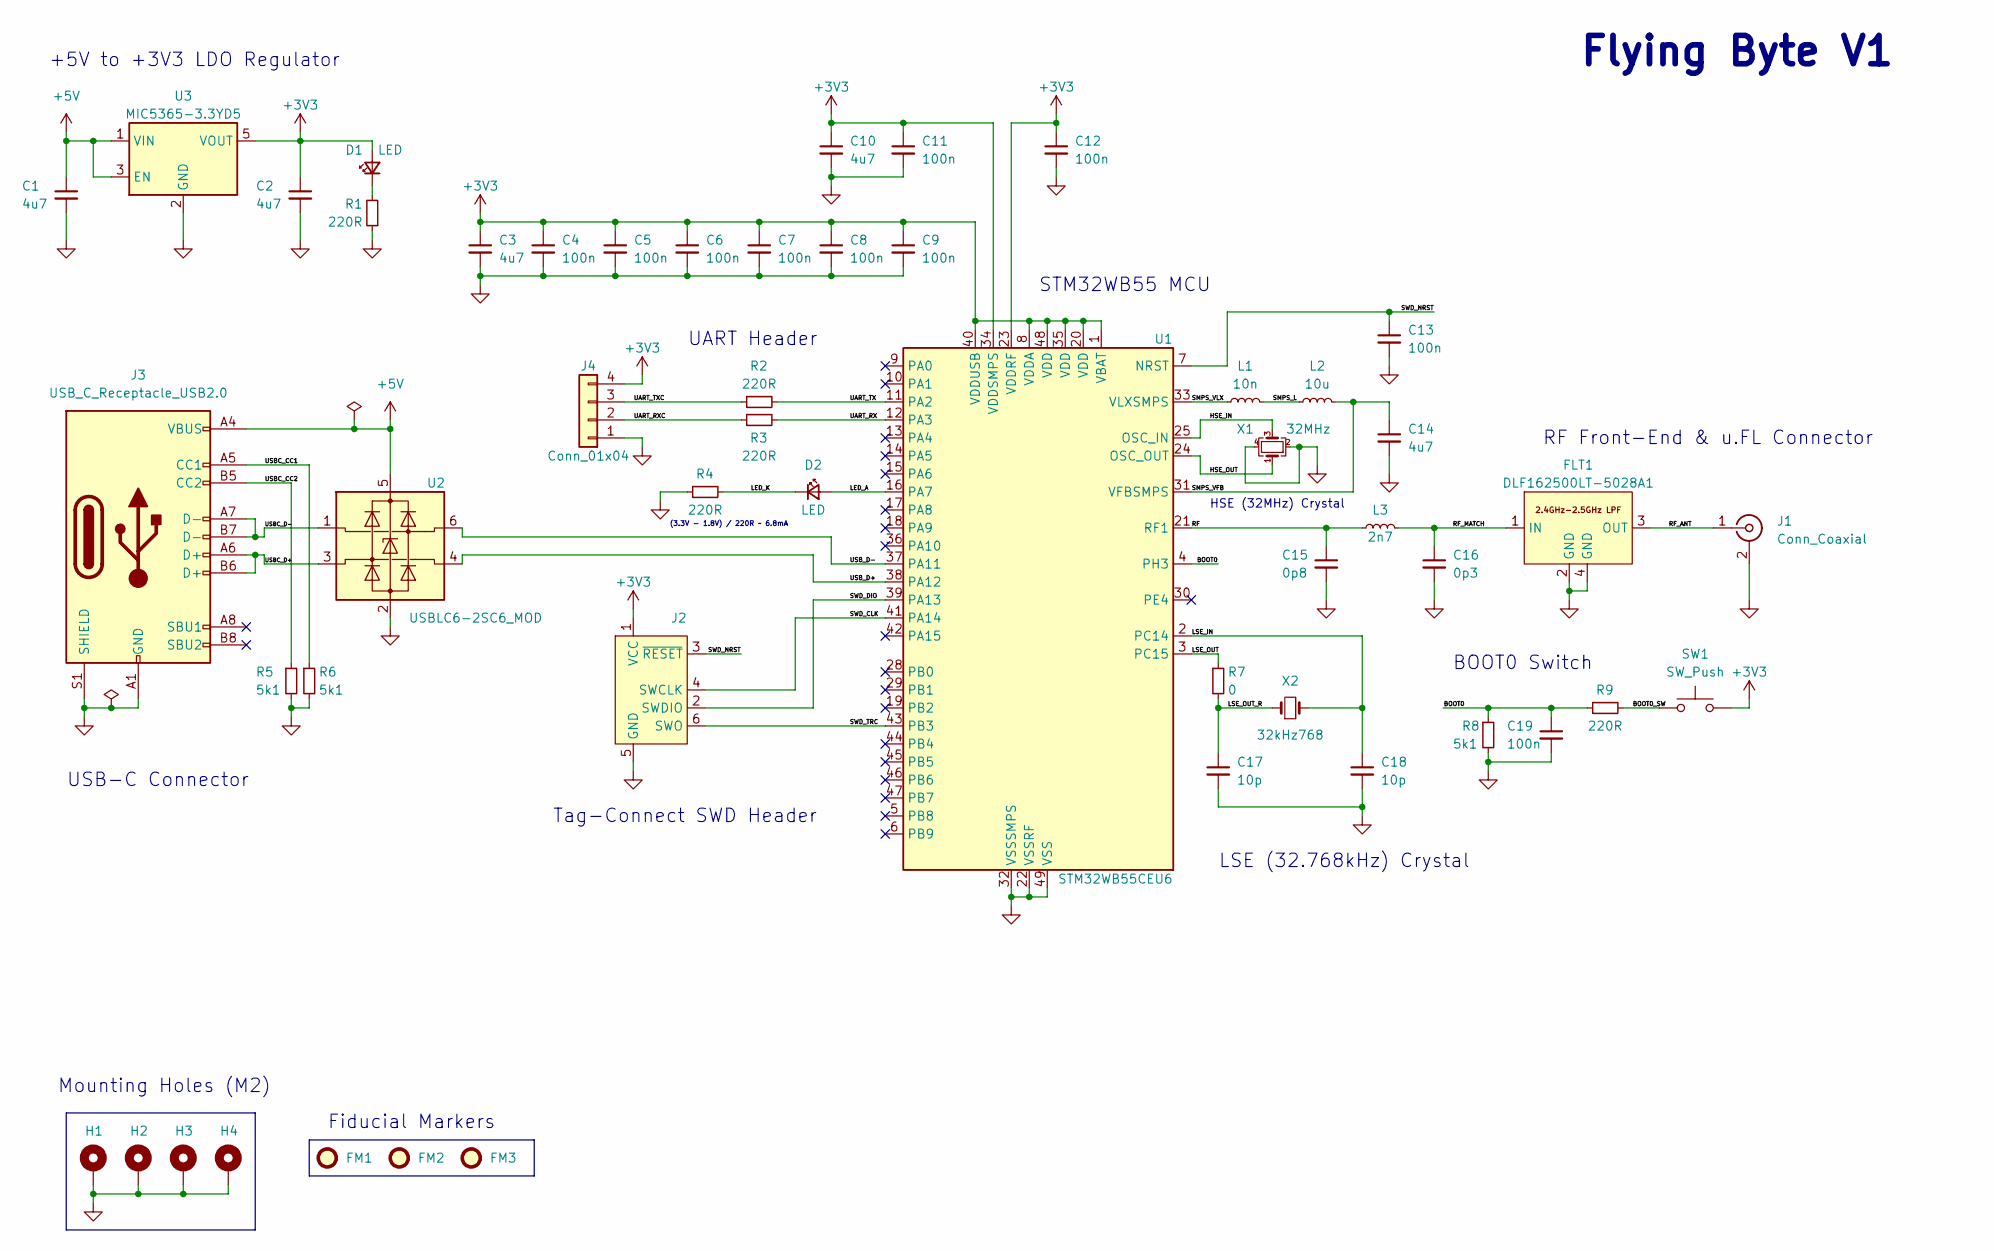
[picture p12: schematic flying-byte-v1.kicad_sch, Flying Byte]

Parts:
C1, C2, C3, C10, C14: 4u7; C_0603_1608Metric; Manufacturer Part Number GRT188R61E475KE13D
C4, C5, C6, C7, C8, C9, C11, C12, C13, C19: 100n; C_0402_1005Metric; Manufacturer Part Number 885012205092
C15: 0p8; C_0402_1005Metric; Manufacturer Part Number GRM1555C1HR80BA01D
C16: 0p3; C_0402_1005Metric; Manufacturer Part Number GRM1555C1HR30WA01D
C17, C18: 10p; C_0402_1005Metric; Manufacturer Part Number C0402C100J5RAC
D1: LED; LED_0402_1005Metric; Manufacturer Part Number FHR1105P-TR
D2: LED; LED_0402_1005Metric; Manufacturer Part Number FHY1105P-TR
FLT1: DLF162500LT-5028A1; Manufacturer Part Number DLF162500LT-5028A1
FM1, FM2, FM3: Fiducial; Fiducial_1mm_Mask2mm
H1, H2, H3, H4: MountingHole_Pad; MountingHole_2.2mm_M2_Pad
J1: Conn_Coaxial; U.FL_Hirose_U.FL-R-SMT-1_Vertical; Manufacturer Part Number U.FL-R-SMT(01)
J2: Conn_ARM_SWD_TagConnect_TC2030; Tag-Connect_TC2030-IDC-FP_2x03_P1.27mm_Vertical
J3: USB_C_Receptacle_USB2.0; USB_C_Receptacle_GCT_USB4105-xx-A_16P_TopMnt_Horizontal; Manufacturer Part Number USB4105-GF-A
J4: Conn_01x04; Molex_PicoBlade_53048-0410_1x04_P1.25mm_Horizontal; Manufacturer Part Number 53048-0410
L1: 10n; L_0402_1005Metric; Manufacturer Part Number LQG15WZ10NJ02D
L2: 10u; L_0805_2012Metric; Manufacturer Part Number LQM21FN100M80L
L3: 2n7; L_0402_1005Metric; Manufacturer Part Number LQG15HS2N7S02D
R1, R2, R3, R4, R9: 220R; R_0402_1005Metric; Manufacturer Part Number RNCF0402BKE220R
R5, R6, R8: 5k1; R_0402_1005Metric; Manufacturer Part Number RNCF0402BKE5K10
R7: 0; R_0402_1005Metric; Manufacturer Part Number MCS04020Z0000ZE000
SW1: SW_Push; SW_SPST_CK_RS282G05A3; Manufacturer Part Number RS282G05A3SMRT
U1: STM32WB55CEU6; QFN-48-1EP_7x7mm_P0.5mm_EP5.6x5.6mm; Manufacturer Part Number STM32WB55CEU6
U2: USBLC6-2SC6_MOD; SOT-23-6; Manufacturer Part Number USBLC6-2SC6
U3: MIC5365-3.3YD5; SOT-23-5; Manufacturer Part Number MIC5365-3.3YD5-TR
X1: 32MHz; Crystal_SMD_2016-4Pin_2.0x1.6mm; Manufacturer Part Number NX2016SA-32M-EXS00A-CS06465
X2: 32kHz768; Crystal_SMD_2012-2Pin_2.0x1.2mm; Manufacturer Part Number NX2012SA-32.768K-STD-MUB-1

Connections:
+3V3: C2.1, C3.1, C4.1, C5.1, C6.1, C7.1, C8.1, C9.1, C10.1, C11.1, C12.1, D1.2 (A), J2.1 (VCC), J4.4, SW1.2, U1.1 (VBAT), U1.8 (VDDA), U1.20 (VDD), U1.23 (VDDRF), U1.34 (VDDSMPS), U1.35 (VDD), U1.40 (VDDUSB), U1.48 (VDD), U3.5 (VOUT)
+5V: C1.1, J3.A4 (VBUS), J3.A9 (VBUS), J3.B4 (VBUS), J3.B9 (VBUS), U2.5 (VBUS), U3.1 (VIN), U3.3 (EN)
/BOOT0: C19.1, R8.1, R9.1, U1.4 (PH3)
/BOOT0_SW: R9.2, SW1.1
/HSE_IN: U1.25 (OSC_IN), X1.3
/HSE_OUT: U1.24 (OSC_OUT), X1.1
/LED_A: D2.2 (A), U1.16 (PA7)
/LED_K: D2.1 (K), R4.2
/LSE_IN: C18.1, U1.2 (PC14), X2.2
/LSE_OUT: R7.1, U1.3 (PC15)
/LSE_OUT_R: C17.1, R7.2, X2.1
/RF: C15.1, L3.1, U1.21 (RF1)
/RF_ANT: FLT1.3 (OUT), J1.1 (In)
/RF_MATCH: C16.1, FLT1.1 (IN), L3.2
/SMPS_L: L1.2, L2.1
/SMPS_VFB: C14.1, L2.2, U1.31 (VFBSMPS)
/SMPS_VLX: L1.1, U1.33 (VLXSMPS)
/SWD_CLK: J2.4 (SWCLK), U1.41 (PA14)
/SWD_DIO: J2.2 (SWDIO), U1.39 (PA13)
/SWD_NRST: C13.1, J2.3 (~RESET), U1.7 (NRST)
/SWD_TRC: J2.6 (SWO), U1.43 (PB3)
/UART_RX: R3.2, U1.12 (PA3)
/UART_RXC: J4.2, R3.1
/UART_TX: R2.2, U1.11 (PA2)
/UART_TXC: J4.3, R2.1
/USBC_CC1: J3.A5 (CC1), R6.1
/USBC_CC2: J3.B5 (CC2), R5.1
/USBC_D+: J3.A6 (D+), J3.B6 (D+), U2.3 (I/O1)
/USBC_D-: J3.A7 (D-), J3.B7 (D-), U2.1 (I/O1)
/USB_D+: U1.38 (PA12), U2.4 (I/O2)
/USB_D-: U1.37 (PA11), U2.6 (I/O2)
GND: C1.2, C2.2, C3.2, C4.2, C5.2, C6.2, C7.2, C8.2, C9.2, C10.2, C11.2, C12.2, C13.2, C14.2, C15.2, C16.2, C17.2, C18.2, C19.2, FLT1.2 (GND), FLT1.4 (GND), H1.1, H2.1, H3.1, H4.1, J1.2 (Ext), J2.5 (GND), J3.A1 (GND), J3.A12 (GND), J3.B1 (GND), J3.B12 (GND), J3.S1 (SHIELD), J4.1, R1.1, R4.1, R5.2, R6.2, R8.2, U1.22 (VSSRF), U1.32 (VSSSMPS), U1.49 (VSS), U2.2 (GND), U3.2 (GND), X1.2, X1.4
unnamed: D1.1 (K), R1.2

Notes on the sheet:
Flying Byte V1
RF Front-End & u.FL Connector
Tag-Connect SWD Header
BOOT0 Switch
STM32WB55 MCU
USB-C Connector
(3.3V - 1.8V) / 220R ~ 6.8mA
Fiducial Markers
+5V to +3V3 LDO Regulator
UART Header
Mounting Holes (M2)
HSE (32MHz) Crystal
LSE (32.768kHz) Crystal

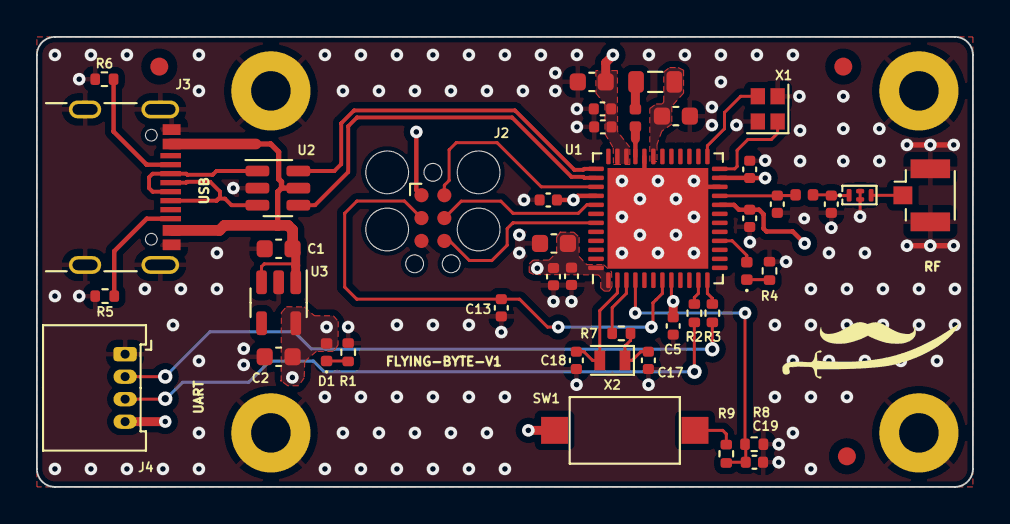
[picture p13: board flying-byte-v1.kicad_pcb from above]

Board: 4 copper layers, 52.0 x 25.0 mm, 51 parts (0 on the bottom side), 33 nets.

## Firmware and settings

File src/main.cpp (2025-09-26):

/**
 * @file 		  MySoilSensorESP32.cpp
 *
 * Author		: Bernd Waldmann
 * Created		: 14-May-2024
 * Tabsize		: 4
 * 
 * This Revision: $Id: main.cpp 1860 2025-09-26 20:05:18Z  $
 */

/*
   Copyright (C) 2024,2025 Bernd Waldmann

   This Source Code Form is subject to the terms of the Mozilla Public License, 
   v. 2.0. If a copy of the MPL was not distributed with this file, You can 
   obtain one at http://mozilla.org/MPL/2.0/

   SPDX-License-Identifier: MPL-2.0
*/

/**
 * @brief Multi-channel soil moisture sensor, reporting via MQTT,
 * using an ESP32 module
 */

//==============================================================================

//----- C standard headers
#include <stddef.h>
#include <stdlib.h>
#include <stdbool.h>
#include <inttypes.h>
#include <time.h>
#include <stdarg.h>

//----- Espressif libraries
#include <rom/rtc.h>            // Apache-2.0 license
#include <soc/rtc_cntl_reg.h>   // Apache-2.0 license
#include <driver/rtc_io.h>      // Apache-2.0 license
#include <esp_wifi.h>           // Apache-2.0 license

//----- Arduino libraries
#include <Arduino.h>            // LGPLv2.1+ license
#include <SPI.h>                // LGPLv2.1+ license
#include <WiFi.h>               // LGPLv2.1+ license
#include <ArduinoOTA.h>         // LGPLv2.1+ license, https://github.com/jandrassy/ArduinoOTA
#include <ArduinoJSON.h>        // MIT license, https://github.com/bblanchon/ArduinoJson
#include <PubSubClient.h>       // MIT license, https://github.com/knolleary/pubsubclient
#include <HTTPUpdate.h>         // LGPLv2.1+ license

//----- my headers
#include "ansi.h"
#include "myauth.h"
#include "MyWifi.h"
#include "SimpleHttpUpdate.h"
#include "SimpleOTA.h"
#include "SimpleReports.h"
#include "SimpleMqttClient.h"


/// version string published at startup.
const char VERSION[] = "$Id: main.cpp 1860 2025-09-26 20:05:18Z  $ built " __DATE__ " " __TIME__;

#define DebugSerial Serial1

//==============================================================================
#pragma region Preferences

#define PIN_AWAKE 23    // show that we are awake, e.g. for oscilloscope trigger

//----- battery voltage measurement

#define BAT_R1 470      // from Vbat to ADC
#define BAT_R2 470      // from ADC to GND
#define PIN_BATTERY 36  // ADC used to measure battery voltage. Arduino name: A0

//----- serial output

#define MY_BAUD_RATE 115200uL

//----- MQTT settings

#define MQTT_BROKER "ha-server"
#define MQTT_TOPIC_BASE "soil/${HOSTNAME}/"
#define MQTT_PREFIX_CMND "cmd"
#define MQTT_TOPIC_SUBSCRIBE MQTT_TOPIC_BASE MQTT_PREFIX_CMND
// subtopics that we publish under
#define SUBTOPIC_DATA   "state"   // topic is soil/hostname/state
#define SUBTOPIC_INFO   "debug"
#define SUBTOPIC_DEVICE "device"
// subtopics where we receive commands from outside
#define SUBTOPIC_CONFIG "config"
#define SUBTOPIC_CMD    "cmd"
// payloads for the soil/hostname/cmd topic
#define MQTT_CMD_RESET   "reset"   // reset min/max sensor range
#define MQTT_CMD_UPDATE  "update"  // perform HTTP update
#define MQTT_CMD_OTA     "ota"     // wait for OTA update

//----- HTTP server for JSON updates
#ifndef FIRMWARE_NAME
 #define FIRMWARE_NAME "MySoilSensorESP32.bin"
#endif
#define UPDATE_SERVER "http://file-server/ota/"
#define FIRMWARE_PATH UPDATE_SERVER FIRMWARE_NAME

//----- sensor pin connections

/// connect these GPIO to sensor outputs
const int pins_sensor[] = { 
    39,     // GPIO 39 = ADC1_3 = Arduino A3
    34,     // GPIO 34 = ADC1_6 = Arduino A6
    35,     // GPIO 35 = ADC1_7 = Arduino A7
    32      // GPIO 32 = ADC1_4 = Arduino A4
    };   

/// connect these GPIO to sensor VCC
const int pins_power[]  = { 
    25,     // GPIO 25 = ADC2_8
    26,     // GPIO 26 = ADC2_9
    27,     // GPIO 27 = ADC2_7
    4       // GPIO 4  = ADC2_0
    };    

/// no of sensor channels
const size_t NCHANNELS = sizeof pins_sensor / sizeof pins_sensor[0];

/// max expected ADC value in millivolts
const unsigned ADC_RANGE_MV = 3000;
/// max voltage from an unconnected input with pulldown
const unsigned ALMOST_ZERO_MV = 400;
/// must have seen this much swing to consider measurement valid, in milllivolts
const unsigned MIN_SENSOR_DYNAMIC_RANGE = 100;

//------------------------------------------------------------------------------
#pragma endregion
//==============================================================================
#pragma region Configuration

//----- Timing phrases
#define SECONDS		
#define MINUTES 	* 60uL SECONDS
#define HOURS 		* 60uL MINUTES
#define DAYS		* 24uL HOURS

#define SIGNATURE 0xDEADBEEF

struct Configuration {
    unsigned signature;
    unsigned meas_interval;     // interval between measurements [s]
    unsigned info_interval;     // interval between debug reports [s]
    unsigned powerup;           // time to power up sensors [ms]
};

const Configuration defaultConfiguration = {
    .signature = SIGNATURE,
    .meas_interval = 30 MINUTES,
    .info_interval = 6 HOURS,
    .powerup = 150
};

RTC_DATA_ATTR Configuration config;

bool config_changed = false;

void setConfiguration( const char* json )
{
    JsonDocument doc;
    DeserializationError error = deserializeJson(doc, json);
    if (error) return;
    config.info_interval = doc["info"] | config.info_interval;
    config.meas_interval = doc["meas"] | config.meas_interval;
    config.powerup = doc["powerup"] | config.powerup;
    config_changed = true;
}


//------------------------------------------------------------------------------
#pragma endregion
//==============================================================================
#pragma region Timing

/*
    Delays and measurement interval are specified in milliseconds
    an int32_t can represent up to 25 days in milliseconds

    Uptime and longer intervals are specified in seconds
    an int32_t can represent up to 68 years in seconds
*/
//#define QUICK

#ifdef QUICK    // shortened timing, for debugging only, may be defined in myauth.h
 // minimum time between refreshes
 const unsigned long SOIL_REPORT_INTERVAL_S = 30 SECONDS;  
 const unsigned long INFO_REPORT_INTERVAL_S = 60 SECONDS;
  // ignore the first few minutes, before th user places the sensor in the soil
  const unsigned long IGNORE_FIRST           = 30 SECONDS;
#else
 // minimum time between refreshes
 #define SOIL_REPORT_INTERVAL_S config.meas_interval
 #define INFO_REPORT_INTERVAL_S config.info_interval
  // ignore the first few minutes, before the user places the sensor in the soil
  const unsigned long IGNORE_FIRST = 5 MINUTES;
#endif
#define CYCLES_PER_FRESH_CONNECT (1 DAYS / SOIL_REPORT_INTERVAL_S)

#define SENSOR_RAMPUP_MS config.powerup

#define DNS_WAIT_MS   100   // how long to wait for DNS response [ms]
#define DNS_RETRY       3   // how many times to retry DNS request

#define MQTT_WAIT_MS  100   // how long to wait for connect to MQTT broker [ms]
#define MQTT_RETRY      3   // how many times to retry connect to MQTT broker

//------------------------------------------------------------------------------
#pragma endregion
//==============================================================================
#pragma region Global variables

bool request_ota = false;       // flag, enable OTA and don't go to sleep
bool request_update = false;    // flag, perform HTTP update
bool request_reset = false;     // flag, reset measurement range
bool firstRun = false;          // flag, this is not waking up from deep sleep

//----- timing measurements to be reported
/// took this long to connect to MQTT broker [ms]
uint32_t dur_mqtt;                
/// took this long to look up MQTT broker hostname [ms]
uint32_t dur_dns;                 
/// how long were we awake? Remember in RTC memory and report next time [ms]
RTC_DATA_ATTR unsigned dur_wake;
/// how long did it take to disconnect from WiFi AP? Remember in RTC memory and report next time [ms]
RTC_DATA_ATTR unsigned dur_disconnect;
/// how many times did we fail to connect, since last successful connection?
RTC_DATA_ATTR unsigned lastCycleFailed;

#ifdef PIN_BATTERY
 unsigned battery_mV;                ///< measured battery voltage, in millivolts
#endif

String Uptime;                  ///< total uptime, including periods of sleep

/// count # of times we have woken up from sleep
RTC_DATA_ATTR unsigned bootCount;       
/// last time battery etc was reported
RTC_DATA_ATTR time_t lastDebugReport_s; 

//----- soil moisture measurements
/// absolute measurements of sensor output [mV]
int sensor_abs[NCHANNELS];  
/// sensor output relative to observed range [promille]
int sensor_rel[NCHANNELS];  

// remember min/max values beyond sleep
struct SensorRange { 
    int vmin; 
    int vmax; 
    bool valid; 
    void reset() { vmin=ADC_RANGE_MV; vmax=0; valid=false; }
};
RTC_DATA_ATTR SensorRange ranges[NCHANNELS];

PubSubClient mqttClient(wifiClient);
SimpleMqttClient simpleMqttClient(mqttClient,MQTT_BROKER);

//------------------------------------------------------------------------------
#pragma endregion
//==============================================================================
#pragma region Little helpers

String formatUptime( time_t now )
{
    char buf[20];

    long seconds = now; 
    long days = seconds / (24 * 60 * 60L);
    seconds -= days * (24 * 60 * 60L);
    long hours = seconds / (60 * 60L);
    seconds -= hours * (60 * 60L);
    long minutes = seconds / 60;
    // like "999d 23:59"
    snprintf( buf, sizeof buf, "%ldd %ld:%02ld", days, hours, minutes );
    return String(buf);
}


/**
 * @brief get IP address from server name, via DNS
 * 
 * @param servername    name to be looked up
 * @param ip            returns IP address here
 * @return true         if lookup successful
 * @return false        if failed
 * 
 * As a side effect update `dur_dns` global variable
 */
bool dns_lookup( const char* servername, IPAddress& ip )
{
    uint32_t t_begin, t_end;
    int ret;

    t_begin = millis();
    for (int i=0; i<DNS_RETRY; i++) {
        ret=WiFi.hostByName(servername, ip); 
        if (1 == ret) {
            t_end = millis();
            dur_dns = t_end - t_begin;       
            log_i("'%s' is %s (" ANSI_BRIGHT_MAGENTA "%u" ANSI_RESET " ms)",
                servername, ip.toString().c_str(), dur_dns );
            return true;
        } else {
            log_e("failed DNS lookup, error %d",ret);
            delay(DNS_WAIT_MS);   
        }
    }
    return false;
}

//------------------------------------------------------------------------------
#pragma endregion
//==============================================================================
#pragma region JSON reports


char msgbuf[256];

/**
 * @brief Create JSON record with debug information for publishing via MQTT
 * 
 * @return const char*  Pointer to static buffer with JSON string
 */
 const char* debug_to_json()
{
    JsonDocument doc;

    doc["Boot"] = bootCount;
#ifdef PIN_BATTERY
    doc["Battery"] = battery_mV;
#endif
    doc["Uptime"] = Uptime.c_str();

    serializeJson(doc,msgbuf);
    return msgbuf;
}


/**
 * @brief Create JSON record with measured parameters for publishing via MQTT
 * 
 * @return const char*  Pointer to static buffer with JSON string
 */
const char* state_to_json()
{
    JsonDocument doc;
    JsonArray vabs = doc["abs"].to<JsonArray>();
    JsonArray vrel = doc["rel"].to<JsonArray>();
    for (int i=0; i<NCHANNELS; i++) {
        vabs.add(sensor_abs[i]);
        vrel.add(sensor_rel[i]);
    }
    if (dur_wake)
        doc["wake"] = dur_wake;

    if (dur_disconnect)
        doc["dis"] = dur_disconnect;

    serializeJson(doc,msgbuf);
    return msgbuf;
}


/**
 * @brief Create JSON record with information about WiFi timing, for publishing via MQTT
 * 
 * @return const char*  Pointer to static buffer with JSON string
 */
const char* wifi_to_json()
{
    JsonDocument doc;
   
    reportWifi( doc );
    simpleMqttClient.report(doc);
    doc["fail"] = lastCycleFailed;

    serializeJson(doc,msgbuf);
    return msgbuf;
}


/**
 * @brief Create debug record for publishing via MQTT,
 * with static information about device
 * 
 * @return const char*  Pointer to static buffer with JSON string
 */
const char* device_to_json()
{
    JsonDocument doc;
    unsigned stackHighWaterMark = uxTaskGetStackHighWaterMark(NULL);

    doc["SDK"] = ESP.getSdkVersion();
    //doc["Core"] = ESP.getCoreVersion();
    doc["Heap"] = ESP.getFreeHeap();   
    doc["Stack"] = stackHighWaterMark;

    serializeJson(doc,msgbuf);
    return msgbuf;
}


//------------------------------------------------------------------------------
#pragma endregion
//==============================================================================
#pragma region MQTT stuff

/*
    publish to haus/HOSTNAME/ 
    path                  | content                         |  publish interval
    ----------------------+---------------------------------+------------------
    haus/HOSTNAME/version | version string from SVN         |  once
    haus/HOSTNAME/device  | static info about CPU, Code etc |  once
    haus/HOSTNAME/wifi    | performance parameters          |  every cycle
    haus/HOSTNAME/debug   | device status                   |  every 6h

    subscribe to haus/HOSTNAME/cmd
    payload                 effect
    ---------------------------------------------------------------------------
    reset                   reset ADC ranges
    ota                     do not go to sleep, wait for OTA update
    update                  perform firmware update from HTTP server
    {"key":"val"}           change configuration option `key` to `val`
*/

void active_wait( unsigned ms )
{
    while (ms--) {
        delay(1);
        if (mqttClient.connected()) mqttClient.loop();
    }
}


void mqttPublish( const char* subtopic, const char* message, bool retain=false )
{
    simpleMqttClient.publish(subtopic, message, retain);
}


void onReceive( const char* subtopic, const char* message )
{
    log_i( "MQTT: received '" ANSI_BLUE "%s" ANSI_RESET "' = '" ANSI_BOLD "%s" ANSI_RESET "'",
        subtopic ? subtopic : "(blank)", 
        message ? message : "(blank)" );

    // is it a empty payload? ... just deleting a retained topic, ignore
    if (message==NULL || *message==0) return;

    if (message[0]=='{') {  // looks like a JSON string, must be a config message
        setConfiguration( message );
    } else if (!strcmp(message,MQTT_CMD_OTA)) {
        request_ota = true;
    } else if (!strcmp(message,MQTT_CMD_UPDATE)) {
        request_update = true;
    } else if (!strcmp(message,MQTT_CMD_RESET)) {
        request_reset = true;
    }
    // acknowledge by deleting retained message
    mqttPublish( MQTT_PREFIX_CMND, NULL, true ); 
}


bool mqttSetup()
{
    bool ok = simpleMqttClient.begin( MQTT_TOPIC_SUBSCRIBE, MQTT_TOPIC_BASE );
    if (ok) {
        simpleMqttClient.setCallback(onReceive);
        active_wait(10);
    }
    return ok;
}

//------------------------------------------------------------------------------
#pragma endregion
//==============================================================================
#pragma region ADC measurement


// qsort requires you to create a sort function
int sorter(const void *cmp1, const void *cmp2)
{
  // Need to cast the void * to int *
  unsigned a = *((unsigned *)cmp1);
  unsigned b = *((unsigned *)cmp2);
  // The comparison
  return a > b ? -1 : (a < b ? 1 : 0);
}


/**
 * @brief Read ADC, and do some primitive noise reduction by averaging multiple
 * samples
 * 
 * @param pin   ESP32 pin number
 * @return unsigned   measured voltage in millivolts
 */
unsigned readSensor( int pin )
{
    unsigned voltage;
    const unsigned NSAMPLES = 20;
    unsigned samples[NSAMPLES];

    // ignore 1st measurement
    voltage = analogReadMilliVolts(pin);
    // take multiple samples
    for (int i=0; i<NSAMPLES; i++)
        samples[i] = analogReadMilliVolts(pin);
    // sort
    qsort( samples, NSAMPLES, sizeof(samples[0]), sorter );
    // average all measurements except for highest and lowest
    unsigned sum=0;
    for (int i=1; i<NSAMPLES-1; i++)
        sum += samples[i];
    voltage = sum / (NSAMPLES-2);

    return voltage;
}


/**
 * @brief take measurement for a single sensor, store result in global vars
 * 
 * @param ch logical channel no [0..3]
 */
void measureSensor( int ch )
{
    unsigned voltage = readSensor(pins_sensor[ch]);
    sensor_abs[ch] = voltage;
    log_i("ch %d = %u mV [range %d .. %d] ",
        pins_sensor[ch], voltage, ranges[ch].vmin, ranges[ch].vmax );

    SensorRange& r = ranges[ch];
    if (voltage < ALMOST_ZERO_MV) {
        r.reset();
    } else {
        if (voltage > r.vmax)
            r.vmax = voltage;
        if (voltage < r.vmin)
            r.vmin = voltage;
        r.valid = 
            ((r.vmax - r.vmin) > MIN_SENSOR_DYNAMIC_RANGE)
            && (r.vmin < ADC_RANGE_MV)
            && (r.vmax > 0)
            ;
    }

    sensor_rel[ch] = (r.valid) ? 1000 - (1000 * (voltage-r.vmin) / (r.vmax-r.vmin)) : -1;
}


/**
 * @brief Turn ON power for all 4 sensors
 * 
 */
void powerSensors()
{
    for (auto pin : pins_power) {
        pinMode( pin, OUTPUT );
        digitalWrite( pin, HIGH );
    }
}


/**
 * @brief Turn OFF power for all 4 sensors
 * 
 */
void poweroffSensors()
{
    for (auto pin : pins_power) {
        digitalWrite( pin, LOW );
    }
    delay(10);
    for (auto pin : pins_power) {
        pinMode(pin,INPUT);
    }
}

//------------------------------------------------------------------------------
#pragma endregion
//==============================================================================
#pragma region Arduino standard functions

/**
 * @brief Standard Arduino framework function, called after power-on 
 * or after waking up from deep sleep.
 * 
 */
void setup()
{
    uint32_t t_begin, t_end;

//----- signal start of wake phase (oscilloscope trigger)
#ifdef PIN_AWAKE
    pinMode( PIN_AWAKE, OUTPUT );
    digitalWrite( PIN_AWAKE, HIGH );
#endif

    Serial1.begin(MY_BAUD_RATE,SERIAL_8N1,16,17);
    Serial1.setDebugOutput(true);  

  	int rtc_reset_reason = rtc_get_reset_reason(0); 

    if ((config.signature != SIGNATURE) || (rtc_reset_reason != DEEPSLEEP_RESET))
        memcpy( &config, &defaultConfiguration, sizeof(Configuration) );
  
    if (rtc_reset_reason != DEEPSLEEP_RESET) { // we did not wake up from deep sleep
        lastCycleFailed = 0;
        firstRun = true;
        memset( ranges, 0, sizeof ranges );
        for (int i=0; i<NCHANNELS; i++) ranges[i].vmin = ADC_RANGE_MV;

        struct timeval tv;
        tv.tv_sec =  0;
        settimeofday(&tv, NULL);        
    }

    request_ota = false;
    uint32_t t_setup_start = millis();  // starts with 0 every time we wake up
    time_t now_s = time(NULL);          // persists across sleep episodes
    if (bootCount==0) now_s=0;
    Uptime = formatUptime(now_s);
    bootCount++;
    // ignore the first 5min or so of sensor readings, to give the op time to place the sensor
    bool ignoreSensors = (now_s < (IGNORE_FIRST / 1000uL) );

    WRITE_PERI_REG(RTC_CNTL_BROWN_OUT_REG,0); // disable brownout detection

    DebugSerial.println("====================================================");

//----- measure battery voltage in mV, for later reporting via MQTT

#ifdef PIN_BATTERY
    battery_mV = analogReadMilliVolts( PIN_BATTERY ) * (BAT_R1 + BAT_R2) / BAT_R2;
#endif

//----- power up the sensors ... they need some time to warm up, so do this before Wifi

    unsigned long t_power = millis();
    powerSensors();

//----- report environment -----------------------------------------------------

    log_i( 
        "Chip:" ANSI_BOLD "%s" ANSI_RESET
        " at " ANSI_BOLD "%u" ANSI_RESET " MHz"
        "  Flash:" ANSI_BOLD "%u" ANSI_RESET " K"
        , 
        ESP.getChipModel(),
        (unsigned)ESP.getCpuFreqMHz(),
        (unsigned)(ESP.getFlashChipSize() / 1024)
    );
    log_i(
        "SDK:" ANSI_BOLD "%s" ANSI_RESET
        "  Arduino " ANSI_BOLD "%d.%d.%d" ANSI_RESET
        ,
        ESP.getSdkVersion(),
        ESP_ARDUINO_VERSION_MAJOR, ESP_ARDUINO_VERSION_MINOR, ESP_ARDUINO_VERSION_PATCH
    );
    log_i(
        "Reset:" ANSI_RED ANSI_BOLD "%d" ANSI_RESET
        "  Heap:" ANSI_BOLD "%d" ANSI_RESET
        ,
        rtc_reset_reason,
        ESP.getFreeHeap()
    );
#ifdef PIN_BATTERY
    log_i( "Battery " ANSI_BOLD "%d" ANSI_RESET " mV",
        battery_mV );
#endif

//----- measure sensors

    log_i("SENSOR: wait for power-up (%u ms)", SENSOR_RAMPUP_MS);
    while ( (unsigned long)(millis()-t_power) < SENSOR_RAMPUP_MS ) {
        delay(10);
    }

    if (!ignoreSensors) {   // ignore sensor readings for the first few minutes?
        for (int i=0; i<NCHANNELS; i++) {
            measureSensor(i);
        }
    } 

    poweroffSensors();

//----- turn on Wifi -----------------------------------------------------------

    bool allow_reconnect = true;
    if ((bootCount % CYCLES_PER_FRESH_CONNECT) == 0)  // once every 24h, do a fresh connect
        allow_reconnect = false;
    if (firstRun)
        allow_reconnect = false;
    if (lastCycleFailed)    
        allow_reconnect = false;

    int wifiOk = setupWifi( WIFI_SSID, WIFI_PASSWORD, allow_reconnect );
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
void loop()
{
    if (!request_ota) return;
    if (loopWifi()) return;
	ArduinoOTA.handle();
    DebugSerial.print('.');

    delay(1000);
}

//---------------------------------------------------------------------
#pragma endregion

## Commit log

2024-08-03 additional reporting, updated README and REQUIREMENTS
    [MySoilSensorESP32.kicad_sch, Power consumption.xlsx]
2024-08-05 faster wifi connection
    [Power consumption.xlsx]
2024-08-09 measurements *before* turning on WiFi, and general cleanup
    [Power consumption.xlsx]
2024-08-19 updated documentation
    [Power consumption.xlsx]
2024-10-10 minor cleanup, report more parameetrs
    [Power consumption.xlsx]
2025-03-07 guard against long wake times; remove support for ESP32-C3
2025-03-08 now using default WiFi Tx power; platformio.ini cleanup
2025-03-16 various cleanup and refactoring
    [Power consumption.xlsx]
2025-03-27 further timeouts to limit effect of failed WiFi connects, try again 5min later
    [main.cpp]
